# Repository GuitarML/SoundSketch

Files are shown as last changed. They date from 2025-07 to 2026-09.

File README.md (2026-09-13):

# SoundSketch

Hardware and software for Soundsketch guitar pedal as shown on [Youtube](https://youtu.be/grorq3XL0zQ?si=FIOID7Fv4AuRCGD6)

Borrows from the open source [DaisySeedProjects](https://github.com/bkshepherd/DaisySeedProjects) pedal, but expression and 3 way toggles, and screen/encoder, midi out removed. 

Not all of the Planet Series software modules ported from Funbox have been tested, some code editing may be required. 

IMPORTANT: When ordering assembled Soundsketch PCBs from JLCPcb or PCBway, you have to manually rotate certain components to the correct orientation on their online tool as part of the ordering process. This is required because the part data exported from KiCad to the .pos file is a different standard from what is expected by the manufacturer. Use the KiCad PCB view to verify correct orientation of ICs and diodes when compared to the manufacturer's parts visualization tool. 

Tayda Drill Template:
https://drill.taydakits.com/box-designs/new?public_key=MndaazFjcjJRM3hIUVQxenhPUm1Rdz09Cg==

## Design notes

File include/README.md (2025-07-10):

# Include
This contains the SoundSketch.h header along with custom headers for SoundSketch software.

## Contents
 - expressionHandler: Expression pedal code for the SoundSketch board. Remaps knob controls to use with an expression pedal.

 - SoundSketch.h : Include header file for SoundSketch.  This provides an abstraction for the knobs, switches, and LEDs when writing software for SoundSketch.```

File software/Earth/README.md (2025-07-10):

# Earth (Planet Series)

Earth is a digital plate reverb and octave pedal using the Dattorro algorithm.

app

The Reverb is a modified version of the Dattorro implementation in [VCV rack Plateau](https://github.com/ValleyAudio/ValleyRackFree/tree/main/src/Plateau). 
The polyoctave effect is from: [Terrarium-Poly-Octave](https://github.com/schult/terrarium-poly-octave).

## Controls

| Control | Description | Comment |
| --- | --- | --- |
| Ctrl 1 | PreDelay | Amount of predelay, up to around 700ms |
| Ctrl 2 | Mix  | Dry/Wet mix |
| Ctrl 3 | Decay  | Amount of decay |
| Ctrl 4 | Mod Depth | Intensity of Mod |
| Ctrl 5 | Mod Speed | Rate of Modulation  |
| Ctrl 6 | Filter | Left of center is high cut, right of center is low cut |
| 3-Way Switch 1 | Reverb Size | Left=Small, Center=Med, Right=Big |
| 3-Way Switch 2 | Octave  | Left=None, Center=Octave Up, Right=Octave Up and Down  |
| 3-Way Switch 3 | Footswitch Action | Left=Momentary Freeze, Center=Momentary Overdrive, Right=Momentary Octave | 
| FS 1 | Bypass/Engage |  |
| FS 2 | Footswitch Action | Perform action based on toggle switch 3 |
| LED 1 | Bypass Indicator |  |
| LED 2 | Preset Indicator |  |
| Audio In 1 | Mono In | Right channel ignored |
| Audio Out 1 | Stereo Out  | Stereo Out via TRS |
<br>
### Expression
1. Plug in passive expression pedal into the 1/8" jack on the top left side of pedal. (will need a 1/4" female to 1/8" male TRS adapter)<br>
2. Hold both footswitches until they both light up (more than 0.5 seconds, but less than 2 seconds), you are now in Set Expression mode.<br>
3. Move the expression pedal into the heel position (up) and move any number of knobs to where you want to heel limit to be (for example you could turn Volume down). The right LED should be brighter up to indicate the heel position is ready to set.*<br>
3. Move the expression pedal into the toe position (down) and move any number of knobs to where you want to toe limit to be (for example you could turn Volume up). The Left LED should be brighter to indicate the toe position is ready to set.*<br>
4. Hold both footswitches to exit Set Expression mode. This will activate expression for the moved knobs. The moved knobs will be inactive until Expression Mode is deactivated.<br>
5. Repeat step 2 to reset Expression knobs.<br>
6. Hold both footswitches for 2 seconds or more to clear any Expression action and give control back to the Funbox knobs.<br>
<br>
* Currently, the expression input requires the full range of the expression pedal, in order to detect Up/Down positions. You can sometimes trim the expression pedal to not use the full range, so adjust the trim as necessary.<br>
  Also, some expression pedals have a "Standard" or "Alternate/Other" mode. Funbox should work on the "Standard" mode.<br>

### MIDI Reference

| Control | MIDI CC | Value |
| --- | --- | --- |
| Knob 1 | 14 | 0- 127 |
| Knob 2 | 15 | 0- 127 |
| Knob 3 | 16 | 0- 127 |
| Knob 4 | 17 | 0- 127 |
| Knob 5 | 18 | 0- 127 |
| Knob 6 | 19 | 0- 127 |

## Build

Build with ```make```.

Earth is intended to be used as a submodule in Funbox, and build paths expect to be used as such. The Earth 
code was split out from the Funbox project to preserve the License used in reused/modified code from other projects. 
To build Earth, it is recommended to clone the Funbox project and run "git submodule update --init --recursive" 
to get Earth and all required dependencies. Otherwise, you can download the .bin executable to upload to the Daisy Seed 
from the Releases page.

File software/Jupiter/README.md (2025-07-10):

# Jupiter (Planet Series)

Jupiter is a Stereo Reverb pedal. The reverb used here is from the [CloudSeed plugin](https://github.com/ValdemarOrn/CloudSeed) (MIT License). It is the same reverb from the Neptune pedal, 
but more EQ controls are exposed to the user, specifically the post reverb low and high shelf filters, both the frequency cutoff and gain.

app

## Controls

| Control | Description | Comment |
| --- | --- | --- |
| Ctrl 1 | Reverb Decay | Increases the decay time of the reverb, about 300ms to 60 seconds, exponential taper (noon is 2 seconds decay) |
| Ctrl 2 | Low Shelf Frequency  | Log Taper 20Hz to 1000Hz, noon is about 200Hz |
| Ctrl 3 | High Shelf Frequency  | Log Taper 400 Hz to 20000Hz, noon is about 4300Hz |
| Ctrl 4 | Mix | Dry to Wet mix |
| Ctrl 5 | Low Shelf Gain | Low shelf cut, from 100% cut to 0.0 gain at max knob  |
| Ctrl 6 | High Shelf Gain | High shelf cut, from 100% cut to 0.0 gain at max knob |
| 3-Way Switch 1 | Lush Level | Amount of "Lushness", low, medium, high |
| 3-Way Switch 2 | Modulation Level  |  Sets the modulation amount and rate, low, medium, high  |
| 3-Way Switch 3 | PreDelay | Sets predelay, 0, 100ms, 200ms | 
| FS 1 | Bypass/Engage |  |
| FS 2 | Preset | Hold to save preset, press to engage/disengage preset. Saves between power cycles. |
| LED 1 | Bypass Indicator |  |
| LED 2 | Preset Indicator |  |
| Audio In 1 | Stereo In | Right channel ignored if MISO Mode turned on |
| Audio Out 1 | Stereo Out  |  |
<br>
### Expression
1. Plug in passive expression pedal into the 1/8" jack on the top left side of pedal. (will need a 1/4" female to 1/8" male TRS adapter)<br>
2. Hold both footswitches until they both light up (more than 0.5 seconds, but less than 2 seconds), you are now in Set Expression mode.<br>
3. Move the expression pedal into the heel position (up) and move any number of knobs to where you want to heel limit to be (for example you could turn Volume down). The right LED should be brighter up to indicate the heel position is ready to set.*<br>
3. Move the expression pedal into the toe position (down) and move any number of knobs to where you want to toe limit to be (for example you could turn Volume up). The Left LED should be brighter to indicate the toe position is ready to set.*<br>
4. Hold both footswitches to exit Set Expression mode. This will activate expression for the moved knobs. The moved knobs will be inactive until Expression Mode is deactivated.<br>
5. Repeat step 2 to reset Expression knobs.<br>
6. Hold both footswitches for 2 seconds or more to clear any Expression action and give control back to the Funbox knobs.<br>
<br>
* Currently, the expression input requires the full range of the expression pedal, in order to detect Up/Down positions. You can sometimes trim the expression pedal to not use the full range, so adjust the trim as necessary.<br>
  Also, some expression pedals have a "Standard" or "Alternate/Other" mode. Funbox should work on the "Standard" mode.<br>

### MIDI Reference

| Control | MIDI CC | Value |
| --- | --- | --- |
| Knob 1 | 14 | 0- 127 |
| Knob 2 | 15 | 0- 127 |
| Knob 3 | 16 | 0- 127 |
| Knob 4 | 17 | 0- 127 |
| Knob 5 | 18 | 0- 127 |
| Knob 6 | 19 | 0- 127 |

## Build

Before building Jupiter, you must build Cloudseed with ```make``` in the CloudSeed folder.

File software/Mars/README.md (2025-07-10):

# Mars (Planet Series)

Mars is an amp sim / delay pedal. It includes 3 neural models, 3 Impulse Responses (Cab Sim), and a delay effect with dotted 8th and triplett modes.

Neural Network inference for the amp/pedal models uses [RTNeural](https://github.com/jatinchowdhury18/RTNeural)
The Impluse Response code is a modified version of the IR processing in the [NAM plugin](https://github.com/sdatkinson/NeuralAmpModelerPlugin) (MIT License) 

Note: Due to the processing power required for the neural models and IRs, Mars is a mono effect, which on the Funbox pedal is copied left to right channel for output. 
If a stereo signal is going into the input, Mars will only take the left channel for processing.

app

## Controls

| Control | Description | Comment |
| --- | --- | --- |
| Ctrl 1 | Gain | Increases the input gain to the neural model |
| Ctrl 2 | Mix | Mix control between the amp and delay |
| Ctrl 3 | Level | Overall volume output |
| Ctrl 4 | Filter | Lowpass filter left of center, highpass right of center |
| Ctrl 5 | Delay Time | Delay time 0 to 2 seconds.  |
| Ctrl 6 | Delay Feedback | Delay Feedback (how long delay takes to fade out) |
| 3-Way Switch 1 | Amp/Model Select | 3 available models, default: left: Matchless SC30, center: Klon pedal, right: Mesa iib |
| 3-Way Switch 2 | IR Select |  3 available IRs, default: left: Proteus (from GuitarML Proteus plugin), center: American, right: Rectifier |
| 3-Way Switch 3 | Delay Mode | left: normal, center: dotted 8th, right: triplett |
| Dip Switch 1 | Amp On/Off | Engage/Disengage Neural model |
| Dip Switch 2 | IR On/Off| Engage/Disengage IR |
| FS 1 | Bypass |  |
| FS 2 | Preset | Hold to save preset, press to engage/disengage preset. Saves between power cycles. |
| LED 1 | Bypass Indicator |  |
| LED 2 | Preset Indicator |  ||
| Audio In 1 | Mono In (Left Channel) | Right channel ignored if using TRS  |
| Audio Out 1 | Mono Out  | Left channel copied to Right Channel if using TRS |

## Build

Mars runs in SRAM memory on the Daisy Seed. You must use the Bootloader to load the executable.

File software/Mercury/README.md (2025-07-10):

# Mercury (Planet Series)

Mercury is an amp sim using Neural Amp Modeler (NAM). It includes 9 custom size neural models and a 4 band EQ (Bass, Mid, Treble, Presence).
It is intended to be used with a separate IR/CabSim, or an actual amp (no cab modelling on Mercury).

Neural Network inference for the amp/pedal models uses [RTNeural](https://github.com/jatinchowdhury18/RTNeural) with [RTNeural-NAM](https://github.com/jatinchowdhury18/RTNeural-NAM).

Note: Due to the processing power required for the neural models, Mercury is a mono effect, which on the Funbox pedal is copied left to right channel for output. 
If a stereo signal is going into the input, Mercury will only take the left channel for processing.

app

*Models included:
Low Gain:
- Matchless SC30
- Twin Reverb
- Dumble Low Gain (from kit build)

Medium Gain:
- Dumble Higher Gain (from kit build)
- Ethos Tube Pedal
- JCM800 Medium Gain

High Gain:
- Mesa iib
- Splawn
- PRS Archon

## Controls

| Control | Description | Comment |
| --- | --- | --- |
| Ctrl 1 | Gain | Increases the input gain to the neural model up to 2.5x |
| Ctrl 2 | Level | Overall volume |
| Ctrl 3 | Presence | +10/-10 dB Presence control, center is 0. |
| Ctrl 4 | Bass | +10/-10 dB Bass control, center is 0. |
| Ctrl 5 | Mid | +10/-10 dB Mid control, center is 0.  |
| Ctrl 6 | Treble | +10/-10 dB Treble control, center is 0. |
| 3-Way Switch 1 | Amp/Model Group | 3 available groups, default: left: LowGain, center: MedGain, right: HighGain |
| 3-Way Switch 2 | NAM Model Select |  3 available NAM models for each group* |
| 3-Way Switch 3 | Unused |  |
| Dip Switch 1 | |  |
| Dip Switch 2 | |  |
| FS 1 | Bypass |  |
| FS 2 | Preset |  |
| LED 1 | Bypass Indicator |  |
| LED 2 | Preset Indicator |  ||
| Audio In 1 | Mono In (Left Channel) | Right channel ignored if using TRS  |
| Audio Out 1 | Mono Out  | Left channel copied to Right Channel if using TRS |

### MIDI Reference

| Control | MIDI CC | Value |
| --- | --- | --- |
| Knob 1 | 14 | 0- 127 |
| Knob 2 | 15 | 0- 127 |
| Knob 3 | 16 | 0- 127 |
| Knob 4 | 17 | 0- 127 |
| Knob 5 | 18 | 0- 127 |
| Knob 6 | 19 | 0- 127 |

## Build

Mercury runs in SRAM memory on the Daisy Seed. You must use the Bootloader to load the executable.

Mercury is intended to be used as a submodule in Funbox, and build paths expect to be used as such. The Mercury 
code was split out from the Funbox project to preserve the License used in reused/modified code from other projects. 
To build Mercury, it is recommended to clone the Funbox project and run "git submodule update --init --recursive" 
to get Mercury and all required dependencies. Otherwise, you can download the .bin executable to upload to the Daisy Seed 
from the Releases page.

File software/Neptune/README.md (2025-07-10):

# Neptune (Planet Series)

Neptune is a Stereo Reverb/Delay pedal. The reverb used here is from the [CloudSeed plugin](https://github.com/ValdemarOrn/CloudSeed) (MIT License), and the Delay includes normal, octave, and reverse modes.
Neptune is very similar to the GuitarML Atlas pedal. The reverse delay is a modified version of the reverse delay from [Veno-Echo](https://github.com/AdamFulford/Veno-Echo) (MIT License)

app

## Controls

| Control | Description | Comment |
| --- | --- | --- |
| Ctrl 1 | Reverb Decay | Increases the decay time of the reverb |
| Ctrl 2 | Mix (rev/delay mix)  | Mix control between the Dry input and effect, alternate is Reverb/Delay volume ratio |
| Ctrl 3 | Delay Time | Delay time from 0 to 4 seconds |
| Ctrl 4 | Mod (Mod Rate) | Amount of modulation of the reverb, Alternate mode sets is mod rate |
| Ctrl 5 | Reverb LowPass | Delay time 0 to 2 seconds.  |
| Ctrl 6 | Delay Feedback | Delay Feedback (how long delay takes to fade out) |
| 3-Way Switch 1 | Reverb Mode |  left: Factory Chorus, center: Medium Space, right: RubiKai (These mostly match the CloudSeed presets) |
| 3-Way Switch 2 | Routing |  left: Some delay fed to reverb, center: Parallel reverb/delay right: delay into reverb in series |
| 3-Way Switch 3 | Delay Mode | left: normal, center: octave, right: reverse |
| Dip Switch 1 | MISO/Stereo | MISO (Mono in stereo out), or True Stereo |
| Dip Switch 2 |  |  |
| FS 1 | Bypass, hold to put into Alternate mode | Alternate mode indicated by dimmed LED, switches back when let go |
| FS 2 | Preset | Hold to save preset, press to engage/disengage preset. Saves between power cycles. |
| LED 1 | Bypass/Alternate Indicator |  |
| LED 2 | Preset Indicator |  ||
| Audio In 1 | Stereo In | Right channel ignored if MISO Mode turned on |
| Audio Out 1 | Stereo Out  |  |
<br>
### Expression
1. Plug in passive expression pedal into the 1/8" jack on the top left side of pedal. (will need a 1/4" female to 1/8" male TRS adapter)<br>
2. Hold both footswitches until they both light up (more than 0.5 seconds, but less than 2 seconds), you are now in Set Expression mode.<br>
3. Move the expression pedal into the heel position (up) and move any number of knobs to where you want to heel limit to be (for example you could turn Volume down). The right LED should be brighter up to indicate the heel position is ready to set.*<br>
3. Move the expression pedal into the toe position (down) and move any number of knobs to where you want to toe limit to be (for example you could turn Volume up). The Left LED should be brighter to indicate the toe position is ready to set.*<br>
4. Hold both footswitches to exit Set Expression mode. This will activate expression for the moved knobs. The moved knobs will be inactive until Expression Mode is deactivated.<br>
5. Repeat step 2 to reset Expression knobs.<br>
6. Hold both footswitches for 2 seconds or more to clear any Expression action and give control back to the Funbox knobs.<br>
<br>
* Currently, the expression input requires the full range of the expression pedal, in order to detect Up/Down positions. You can sometimes trim the expression pedal to not use the full range, so adjust the trim as necessary.<br>
  Also, some expression pedals have a "Standard" or "Alternate/Other" mode. Funbox should work on the "Standard" mode.<br>

### MIDI Reference

| Control | MIDI CC | Value |
| --- | --- | --- |
| Knob 1 | 14 | 0- 127 |
| Knob 2 | 15 | 0- 127 |
| Knob 3 | 16 | 0- 127 |
| Knob 4 | 17 | 0- 127 |
| Knob 5 | 18 | 0- 127 |
| Knob 6 | 19 | 0- 127 |

## Build

Neptune runs in SRAM memory on the Daisy Seed. You must use the Bootloader to load the executable.
Note: MIDI will not work if you use the Bootloader from the Daisy Web Programmer (it's an old version).

Before building Neptune, you must build Cloudseed with ```make```

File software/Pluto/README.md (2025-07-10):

# Pluto

Pluto is a wacky dual/stereo looper for endless experimentation. Each looper features a variable speed control, smooth or stepped,
and several effects and loop modes. Pluto runs at 96kHz instead of 48kHz, in order to have the best quality when slowing down loops,
but don't worry, lots of aliasing/artifacts are present when strethching audio!

Loops are recorded at the current speed setting. For example, if the speed of Loop A is at 2x and you record a loop, it will sound normal, but turning the speed 
knob down to 1x will play your loop at half speed (and half the samplerate). 

Pluto is in active development, more features coming 

app

## Controls

| Control | Description | Comment |
| --- | --- | --- |
| Ctrl 1 | Looper A Volume |  |
| Ctrl 2 | Looper A Modify | Modifies the current effect applied to loop A (or for Reverb, controls decay time) |
| Ctrl 3 | Looper B Volume |  |
| Ctrl 4 | Looper A Speed/Direction | Speed and direction of Loop A, -2x (reverse) to +2x speed, noon is 1x speed |
| Ctrl 5 | Looper A Modify | Modifies the current effect applied to loop A (or for Reverb, controls decay time) |
| Ctrl 6 | Looper B Speed/Direction | Speed and direction of Loop B, -2x (reverse) to +2x speed, noon is 1x speed |  |
| 3-Way Switch 1 | Looper A/B Speed mode | Left = smooth, Center=Stepped, Right= TBD |
| 3-Way Switch 2 | Live effect select (controls what modify knobs do) | Left=Stability(random variations in playback speed), Center=Filter (LP to the left, HP to the right), Right=Reverb (stereo, ModA is decay, ModB is damping) |
| 3-Way Switch 3 | Loop Record Mode | Left = normal, Center = One Time loop record, Right= Frippertronics (when recording, acts like a delay, applying a decay time to the loop) |
| Dip Switch 1 | MISO/Stereo | Miso only takes the left channel input, and treats each looper as independant. Stereo takes L/R input and treats loopers as connected when recording (Looper B footswitch is inactive in Stereo Mode) |
| Dip Switch 2 | TBD | Want to add a Sync mode here, where the loop time for both A/B are equal |
| FS 1 | Loop A control | Tap once to start recording loop, tap again to stop record and start playback. Double tap to pause loop. Hold to clear loop. Tap again to overdub. Currently no undo function. |
| FS 2 | Loop B control | Same as Loop A |
| LED 1 | Loop A Indicator | Pulses while recording, Solid while playback, blinking while paused. |
| LED 2 | Loop B indicator | Same as Loop A|
| Audio In 1 | Stereo (or MISO) | MISO will use 2 speparate loopers, and copy left channel output to right, Stereo will use 1 looper, and loop A is left channel, loop B is right channel |
| Audio Out 1 | Stereo |  |

<br>
### Expression
Expression Operation: NOTE THAT THIS IS DIFFERENT FROM OTHER PLANET PEDALS**<br>
1. Plug in passive expression pedal into the 1/8" jack on the top left side of pedal. (will need a 1/4" female to 1/8" male TRS adapter)<br>
2. Turn on Dipswitch 3 to enter Set Expression mode, both LEDs should light up, you are now in Set Expression mode.<br>
3. Move the expression pedal into the heel position (up) and move any number of knobs to where you want to heel limit to be (for example you could turn Volume down). The right LED should be brighter up to indicate the heel position is ready to set.*<br>
3. Move the expression pedal into the toe position (down) and move any number of knobs to where you want to toe limit to be (for example you could turn Volume up). The Left LED should be brighter to indicate the toe position is ready to set.*<br>
4. Turn off Dipswitch 3 to exit Set Expression mode and enter Expression Active Mode. <br>
5. Flip Dipswitch 3 on and move expression pedal into both up and down positions without turning any knobs. Flip Dipswitch 3 off to clear expression and give control back to knobs.

<br>
* Currently, the expression input requires the full range of the expression pedal, in order to detect Up/Down positions. You can sometimes trim the expression pedal to not use the full range, so adjust the trim as necessary.<br>
  Also, some expression pedals have a "Standard" or "Alternate/Other" mode. Funbox should work on the "Standard" mode.<br>
<br>
** Since Pluto uses the footswitches for looper funtions, the third dip switch is used to enter/exit Set Expression mode. Flip dipswitch 3 without adjusting any knobs to clear expression settings.

### MIDI Reference

| Control | MIDI CC | Value |
| --- | --- | --- |
| Knob 1 | 14 | 0- 127 |
| Knob 2 | 15 | 0- 127 |
| Knob 3 | 16 | 0- 127 |
| Knob 4 | 17 | 0- 127 |
| Knob 5 | 18 | 0- 127 |
| Knob 6 | 19 | 0- 127 |
| Toggle Left | 21 | 0,1:left ; 2, center; 3 or > right |
| Toggle Center | 22 | 0,1:left ; 2, center; 3 or > right |
| Toggle Right| 23 | 0,1:left ; 2, center; 3 or > right |

## Build

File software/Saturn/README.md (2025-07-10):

# Saturn (Planet Series)

Saturn is a Spectral Delay. It works by using a FFT (Fast Fourier Transform) to split up your signal in the frequency domain and apply different delays to each frequency group. 
Saturn diffracts your signal into "particles", creating a kaleidoscope of sound from your guitar.

This code adapts the FFT code here to run on Funbox hardware:
https://github.com/amcerbu/DaisySTFT

app

## Controls

| Control | Description | Comment |
| --- | --- | --- |
| Ctrl 1 | PreDelay | Adds up to 1 second of delay prior to the spectral delay starting |
| Ctrl 2 | Mix  | Dry/Wet mix |
| Ctrl 3 | Filter  | Lowpass to the left, Highpass to the right |
| Ctrl 4 | Time | 0 to 4 seconds of delay spread in the frequency bins, exact action determined by time toggle |
| Ctrl 5 | Feedback | Amount of feedback, depending on the FDBK toggle  |
| Ctrl 6 | DriftMod | Oscillation rate for drift, 0 to 1Hz |
| 3-Way Switch 1 | Time Mode | Left= Linear increase of delay time as frequency increases (TimeMod controls slope), Center= Sine wave of delay times across frequencies (TimeMod controls frequency) , Right= Random delay time for each line (TimeMod controls spread) |
| 3-Way Switch 2 | Feedback Mode  | Left=Same FDBK across delaylines , Center=linear decrease with frequency increase , Right= random amount of fdbk for each delayline |
| 3-Way Switch 3 | Drift | Left= Predelay not included, modulates delaytime and delayfeedback; Center= No Drift ; Right= Predelay included in drift, causing pitch warping sounds from modulating the predelay line | 
| Dip Switch 1 | Mono (off) / Stereo(on) | Mono mode uses the right channel's delay lines to double the frequency bins used in the spectral delay, (MONO overrides MISO/Stereo switch |
| Dip Switch 2 | MISO (off) /Stereo (on) | MISO (Mono in stereo out), or True Stereo |
| Dip Switch 3 | Stereo Spread Off/On | Places each frequency bin at a random point in the stereo field |
| Dip Switch 4 | On adds feedback of 0.75 to the Predelay |  |
| FS 1 | Bypass/Engage |  |
| FS 2 | Preset | Hold to save preset, press to engage/disengage preset. Saves between power cycles. |
| LED 1 | Bypass Indicator |  |
| LED 2 | Preset Indicator |  |
| Audio In 1 | Stereo In | Right channel ignored if in Mono or MISO mode |
| Audio Out 1 | Stereo Out  | Left channel copied to right if in Mono mode |
<br>
### Expression
1. Plug in passive expression pedal into the 1/8" jack on the top left side of pedal. (will need a 1/4" female to 1/8" male TRS adapter)<br>
2. Hold both footswitches until they both light up (more than 0.5 seconds, but less than 2 seconds), you are now in Set Expression mode.<br>
3. Move the expression pedal into the heel position (up) and move any number of knobs to where you want to heel limit to be (for example you could turn Volume down). The right LED should be brighter up to indicate the heel position is ready to set.*<br>
3. Move the expression pedal into the toe position (down) and move any number of knobs to where you want to toe limit to be (for example you could turn Volume up). The Left LED should be brighter to indicate the toe position is ready to set.*<br>
4. Hold both footswitches to exit Set Expression mode. This will activate expression for the moved knobs. The moved knobs will be inactive until Expression Mode is deactivated.<br>
5. Repeat step 2 to reset Expression knobs.<br>
6. Hold both footswitches for 2 seconds or more to clear any Expression action and give control back to the Funbox knobs.<br>
<br>
* Currently, the expression input requires the full range of the expression pedal, in order to detect Up/Down positions. You can sometimes trim the expression pedal to not use the full range, so adjust the trim as necessary.<br>
  Also, some expression pedals have a "Standard" or "Alternate/Other" mode. Funbox should work on the "Standard" mode.<br>

### MIDI Reference

| Control | MIDI CC | Value |
| --- | --- | --- |
| Knob 1 | 14 | 0- 127 |
| Knob 2 | 15 | 0- 127 |
| Knob 3 | 16 | 0- 127 |
| Knob 4 | 17 | 0- 127 |
| Knob 5 | 18 | 0- 127 |
| Knob 6 | 19 | 0- 127 |

## Build

Saturn compiles for FLASH memory on the Daisy Seed using the standard upload procedure.

## Technical Info:
Saturn uses a FFT with N=1024 and laps=4 (4 overlapping hann windows). This splits the frequencies into N/2=512 frequency bins. 

At 48000kHz samplerate, the bins are split into (samplerate / 2 / #bins) = 46.875 Hz per bin. 

Each bin output is applied to a separate delayline with different time/feedback to create the Spectral Delay. 
I use two DaisySP delaylines for each bin, one for the real component and one for the imaginary component. 

In order to run on the Daisy Seed in Stereo (using two FFTs), the maximum number of bins with delaylines I was able to use was 175. Using
more than 175 caused audio dropouts when running at 48kHz samplerate. You can utilize more bins by running at a lower samplerate, such as 32kHz.

The frequency range of the spectral delay is (#bins * 46.875) = 8203Hz. This is nowhere near the full audible spectrum, but it still sounds pretty good.

When using Mono mode (dipswitch 1 in the off position), I'm able to use 350 frequency bins for a range of 16406Hz, much closer to the full range of the audible frequencies.
See if you can hear the difference!

The custom FFT function "spectraldelay()" and "spectraldelay2()" (for the right channel) is called every N/laps, so 1024/4=256 samples. 
At 48kHz, this means that the spectraldelay function is called 48000/256 = 187.5 times per second. This means that even though we use 
a relatively large number of delaylines, each one only needs to have a size of 187.5 * 4 = 750 for a max of 4 seconds of delay. (compared to 48000 samples per second in the time domain).

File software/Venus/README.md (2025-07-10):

# Venus

Venus is a Spectral Reverb that uses a STFT (Short time Fourier Transform) to operate on your signal in the frequency
domain. It can create lush soundscapes with string-like overtones, detuning, and spectral freeze.  It features
two LoFi modes that reduce the samplerate and two "drift" modes that modulate knob values slowly over time. 

Notes: The Venus pedal runs at 32kHz samplerate and buffersize of 256 in order to run smoothly with the current STFT implementation.
Improving the efficiency of the STFT to run at higher samplerates and lower buffersize is of interest.

app

## Controls

| Control | Description | Comment |
| --- | --- | --- |
| Ctrl 1 | Decay | Decay time of reverb |
| Ctrl 2 | Mix | Dry/Wet mix |
| Ctrl 3 | Damp | Reverb dampening |
| Ctrl 4 | Shimmer Amount | Adds octave shimmer |
| Ctrl 5 | Shimmer Tone | Adds in octave + 5ths to shimmer |
| Ctrl 6 | Detune | Left of noon detunes down, right of noon detunes up |
| 3-Way Switch 1 | Shimmer Mode | left=octave down, center= octave up, right=octave up and octave down |
| 3-Way Switch 2 | LoFi Mode (lofi applied to wet mix only, not dry mix) | left= samplerate of 9600 with lowpass filter, center=None, right= samplerate of 6400, no lowpass filter |
| 3-Way Switch 3 | Drift Mode | left=same as right except at a rate of ~50 seconds, center=none, right=more, oscillates the Damp, Shimmer, ShimmerTone, and Detune controls from the current setting to 0 at a rate of 1 cycle per ~25 seconds |
| Dip Switch 1 | N/A |  |
| Dip Switch 2 | N/A |  |
| Dip Switch 3 | N/A |  |
| Dip Switch 4 | N/A |  |
| FS 1 | Bypass/Engage |  |
| FS 2 | Freeze |  |
| LED 1 | Bypass indicator |  |
| LED 2 | Freeze indicator | |
| Audio In 1 | Mono in | |
| Audio Out 1 | Mono out (left copied to right) |  |

### Expression
1. Plug in passive expression pedal into the 1/8" jack on the top left side of pedal. (will need a 1/4" female to 1/8" male TRS adapter)<br>
2. Hold left footswitche until they both LEDS blink (more than 0.6 seconds, but less than 2 seconds), you are now in Set Expression mode.<br>
3. Move the expression pedal into the heel position (up) and move any number of knobs to where you want to heel limit to be (for example you could turn Volume down). The right LED should be brighter up to indicate the heel position is ready to set.*<br>
3. Move the expression pedal into the toe position (down) and move any number of knobs to where you want to toe limit to be (for example you could turn Volume up). The Left LED should be brighter to indicate the toe position is ready to set.*<br>
4. Hold left footswitch to exit Set Expression mode. This will activate expression for the moved knobs. The moved knobs will be inactive until Expression Mode is deactivated.<br>
5. Repeat step 2 to reset Expression knobs.<br>
6. Hold left footswitch for 2 seconds or more to clear any Expression action and give control back to the Funbox knobs.<br>
<br>
* Currently, the expression input requires the full range of the expression pedal, in order to detect Up/Down positions. You can sometimes trim the expression pedal to not use the full range, so adjust the trim as necessary.<br>
  Also, some expression pedals have a "Standard" or "Alternate/Other" mode. Funbox should work on the "Standard" mode.<br>

### MIDI Reference

| Control | MIDI CC | Value |
| --- | --- | --- |
| Knob 1 | 14 | 0- 127 |
| Knob 2 | 15 | 0- 127 |
| Knob 3 | 16 | 0- 127 |
| Knob 4 | 17 | 0- 127 |
| Knob 5 | 18 | 0- 127 |
| Knob 6 | 19 | 0- 127 |

## Build

Venus runs in Flash memory on the Daisy Seed.

## Acknowledgements

This code adapts the code found here to run a STFT on the Daisy Seed:
https://github.com/amcerbu/DaisySTFT

Which uses the "shyfft" authored by Émilie Gillet of Mutable Instruments:
https://github.com/pichenettes/eurorack

The math used in this reverb is heavily inspired by the Atlantis Reverb by Geraint Luff:
https://geraintluff.github.io/jsfx/#Atlantis%20Reverb

And directly from the examples in this forum post by Geraint Luff:
https://forum.cockos.com/showthread.php?t=225955

The Venus pedal would not be possible without the generosity of smart people sharing their work in the open source community. Thank you!

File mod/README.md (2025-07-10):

# libDaisy Modifications

Replace these files in libDaisy before building libDaisy. This is required to correctly map the controls for SoundSketch hardware.

<br><br>
INSTRUCTIONS:
```
# Replace libDaisy/src/daisy_pedal.h with SoundSketch/mod/daisy_pedal.h
# Replace libDaisy/src/daisy_pedal.cpp with SoundSketch/mod/daisy_pedal.cpp

make -C libDaisy
```

## bksheperd hardware module definitions

These are the hardware definitions for using the bksheperd guitar pedal framework on the SoundSketch. 
Add these two files to the following location in your [DaisySeedProjects](https://github.com/bkshepherd/DaisySeedProjects/tree/main) repo and update 
the guitar_pedal.cpp to use this hardware definition.

Add the guitar_pedal_soundsketch.h and guitar_pedal_soundsketch.cpp file to this location to use this extensive guitar effect framework on the SoundSketch:
https://github.com/bkshepherd/DaisySeedProjects/tree/main/Software/GuitarPedal/Hardware-Modules

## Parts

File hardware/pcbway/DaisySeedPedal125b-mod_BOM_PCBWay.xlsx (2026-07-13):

 |  |  | xxxx xxxx xxxxx xxPCS BOM (Sample Bill of Materials)
Item # | *Designator | *Qty | Manufacturer | *Mfg Part # | Description / Value | *Package/Footprint | Type | Your Instructions / Notes
1 | U4 | 1 | Everlight Elec | H11L1S(TA) | 3V~15V DC SOP-6-2.54mm Logic Output Optoisolators ROHS | SOP-6_2.54mm | SMD
2 | R20 | 1 | UNI-ROYAL(Uniroyal Elec) | 0805W8F4700T5E | 125mW Thick Film Resistors 150V ±100ppm/℃ ±1% 470Ω 0805 Chip Resistor - Surface Mount ROHS | 805 | SMD
3 | J7,J6 | 2 | BOOMELE(Boom Precision Elec) | 2.54-1*20PFemale | 1x20 Through Hole Header | Plugin,P=2.54mm | thru-hole | If these are expensive or difficult to source, I can handle the 20 pin headers myself (customer)
4 | R11,R1,R2,R12,R5,R10,R15,R18,R16,R4,R9 | 11 | UNI-ROYAL(Uniroyal Elec) | 0805W8F2004T5E | 125mW Thick Film Resistors 150V ±100ppm/℃ ±1% 2MΩ 0805 Chip Resistor - Surface Mount ROHS | 805 | SMD
5 | K2,K1 | 2 | Omron Electronics | G6K-2G-Y DC5 | Two Sets of Conversion: 2C (DPDT-Conversion) 1A 5V SMD,6.5x10mm Signal Relays ROHS | SMD,6.5x10mm | SMD
6 | U3 | 1 | Texas Instruments | OPA1652AIDR | Dual Channel SOIC-8 Audio Amplifiers ROHS | SOIC-8 | SMD
7 | U2 | 1 | Microchip Tech | MCP6004T-I/SL | Four channels 1pA 0.6V/us 1MHz Rail-to-rail input, rail-to-rail output 4.5mV SOIC-14 Operational Amplifier ROHS | SOIC-14 | SMD
8 | R14,R13 | 2 | UNI-ROYAL(Uniroyal Elec) | 0805W8F1000T5E | 125mW Thick Film Resistors 150V ±100ppm/℃ ±1% 100Ω 0805 Chip Resistor - Surface Mount ROHS | 805 | SMD
9 | C10,C9 | 2 | Samsung Electro-Mechanics | CL21C222JBFNNNE | 50V 2.2nF C0G ±5% 0805 Multilayer Ceramic Capacitors MLCC - SMD/SMT ROHS | 805 | SMD
10 | C1,C8,C7,C12,C4,C11,C16,C15 | 8 | Samsung Electro-Mechanics | CL21A106KAYNNNE | 25V 10uF X5R ±10% 0805 Multilayer Ceramic Capacitors MLCC - SMD/SMT ROHS | 805 | SMD
11 | R23,R22,R21,R25,R24 | 5 | UNI-ROYAL(Uniroyal Elec) | 0805W8F1001T5E | 125mW Thick Film Resistors 150V ±100ppm/℃ ±1% 1kΩ 0805 Chip Resistor - Surface Mount ROHS | 805 | SMD
12 | D3,D4 | 2 | Shandong Jingdao Microelectronics | 1N4007W | 1A Independent Type 1kV 1.1V@1A SOD-123FL Diodes - General Purpose ROHS | SOD-123FL | SMD
13 | R7,R8 | 2 | UNI-ROYAL(Uniroyal Elec) | 0805W8F3301T5E | 125mW Thick Film Resistors 150V ±100ppm/℃ ±1% 3.3kΩ 0805 Chip Resistor - Surface Mount ROHS | 805 | SMD
14 | C14,C13,C3,C2,C6,C17,C5 | 7 | YAGEO | CC0805KRX7R9BB104 | 50V 100nF X7R ±10% 0805 Multilayer Ceramic Capacitors MLCC - SMD/SMT ROHS | 805 | SMD
15 | U7 | 1 | Microchip Tech | MCP6002T-I/SN | Dual 1pA 0.6V/us 1MHz SOIC-8 Operational Amplifier ROHS | SOIC-8 | thru-hole
16 | U5,U6 | 2 | Littelfuse/IXYS | CPC1018NTR | 1 Form A(SPST-NO) 1.2V 60V 580mΩ 600mA SOP-4-2.54mm Solid State Relays (MOS Output) ROHS | SOP-4-2.54mm | SMD
17 | R3,R6 | 2 | UNI-ROYAL(Uniroyal Elec) | 0805W8F1003T5E | 125mW Thick Film Resistors 150V ±100ppm/℃ ±1% 100kΩ 0805 Chip Resistor - Surface Mount ROHS | 805 | SMD
18 | D2 | 1 | ST(Semtech) | 1N4148W | 75V Independent Type 1V@50mA 4ns 150mA SOD-123 Switching Diodes ROHS | SOD-123 | SMD
19 | J2, J4, J5, J9 | 4 | Neutrik | NMJ6HCD2 | Audio Connectors (Headphones) ROHS |  | thru-hole
20 | U1 | 1 | STMicroelectronics | LD1117S50CTR | 75dB@(120Hz) 800mA Fixed 5V Positive electrode 15V SOT-223-3 Voltage Regulators - Linear, Low Drop Out (LDO) Regulators ROHS | SOT-223-3 | SMD
21 | R17 | 1 | UNI-ROYAL(Uniroyal Elec) | 0805W8F2200T5E | 125mW Thick Film Resistors 150V ±100ppm/℃ ±1% 220Ω 0805 Chip Resistor - Surface Mount ROHS | 805 | SMD
22 | D1 | 1 | TWGMC | 1N5817W | 20V Independent Type 750mV@3A 1A SOD-123 Schottky Diodes ROHS | SOD-123 | SMD
23 | Q1 | 1 | Jiangsu Changjing Electronics Technology Co., Ltd. | SS8050 | 25V 300mW 200@100mA,1V 1.5A NPN SOT-23 Bipolar (BJT) ROHS | SOT-23-3 | SMD

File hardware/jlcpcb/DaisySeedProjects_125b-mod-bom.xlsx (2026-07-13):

Comment | Designator | Footprint | JLCPCB Part #（optional）
H11L1 | U4 | SOP-6_2.54mm | C78589
470R | R20 | 805 | C17710
1x20 Through Hole Header | J7,J6 |  | C50984
2M | R11,R1,R2,R12,R5,R10,R15,R18,R16,R4,R9 | 805 | C26112
G6K-2G-Y DC5 | K2,K1 | SMD,6.5x10mm | C397140
OPA1652AIDR | U3 | SOIC-8 | C30025
MCP6004T-I/SL | U2 | SOIC-14 | C7378
100R | R14,R13 | 805 | C17408
2.2NF | C10,C9 | 805 | C28260
10UF | C1,C8,C7,C12,C4,C11,C16,C15 | 805 | C15850
1K | R23,R22,R21,R25,R24 | 805 | C17513
1N4007W | D3,D4 | SOD-123FL | C108803
3.3K | R7,R8 | 805 | C26010
100NF | C14,C13,C3,C2,C6,C17,C5 | 805 | C49678
MCP6002T-I/SN | U7 | SOIC-8 | C7377
CPC1018N | U5,U6 | SOP-4-2.54mm | C133069
100K | R3,R6 | 805 | C149504
1N4148W | D2 | SOD-123 | C81598
NMJ6HCD2 | J2, J4, J5, J9 |  | C368502
LD1117S50CTR | U1 | SOT-223-3 | C81157
220R | R17 | 805 | C17557
1N5817 | D1 | SOD-123 | C727113
SS8050 | Q1 | SOT-23-3 | C2150

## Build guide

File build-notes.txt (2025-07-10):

1. Trim the backside midi and expression solder pin joints, they are too tall to fit potentiometers on top. 
   Put potentiometer covers on the bottom of the potentiometers, or they will short out the midi and expression jack leads.

2. Solder potentiometers. Install board into enclosure with potentiometers and switches in place, and tighten jack nuts. 
   This will ensure everything is set properly before soldering. Solder the 6 potentiometers (BUT NOT THE TOGGLE SWITCHES YET).

3. Remove the pcb and inspect. 

4. Solder toggles. VERY IMPORTANT: APPLY ELECTRICAL TAPE TO OUTSIDE OF TOGGLE BLOCKS, OTHERWISE WILL SHORT
   OUT ON THE SIDES OF THE POTENTIOMETER LEADS. Install toggles on pcb, then put pcb into enclosure, tightening
   everything in place (including 4 audio/exp/midi jacks) as with the potentiometers to ensure proper fit. 
   Solder the 3 toggle switches.

5. Solder the 2 LEDs on the pcb. Trim LED leads as neccessary, testing fit into LED bezels before soldering. 
   Solder LEDs onto the pcb and test fit in enclosure. 

6. Solder the power jack wires to the pcb with pcb not installed in enclosure. There is not much room
   in the enclosure with the pcb installed so this makes it easer to solder the power wires. 

7. Install pcb back into enclosure, then fit power jack and power jack nut into enclosure. There is not much room
   between the power jack nut and pcb. Solder the power jack wires to the power jack leads. 

8. Solder the 4 momentary footswitch wires to the momentary footswitches before installing into the enclosure.
   Its easier to do this first. Then install the footswitches into the enclosure and solder footswitch wires to the pcb.

9. Tighten all nuts. Visually inspect and check for anything loose. 

10. Install Daisy Seed and test.

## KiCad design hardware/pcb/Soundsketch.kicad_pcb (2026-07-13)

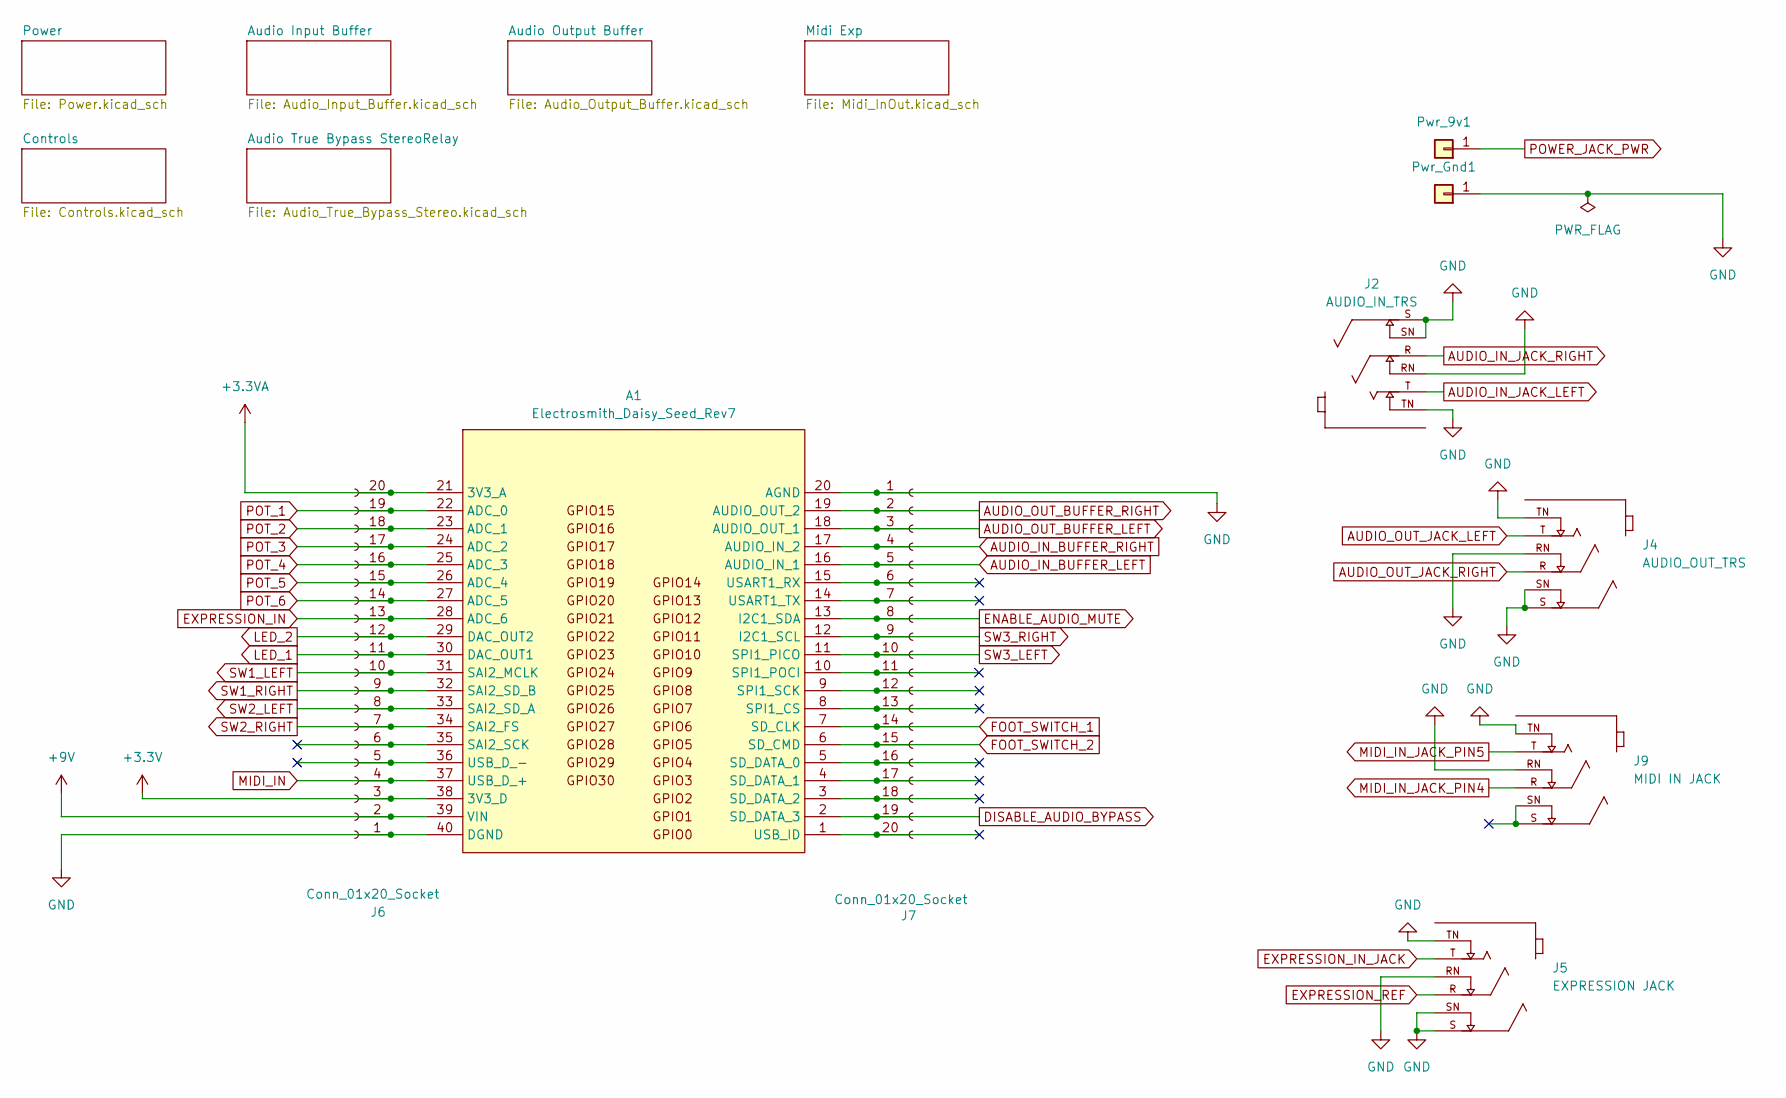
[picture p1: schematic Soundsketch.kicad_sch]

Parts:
A1: Electrosmith_Daisy_Seed_Rev7
J2: AUDIO_IN_TRS; NEUTRIK_NMJ6HCD2; PARTREV 26.02.2021
J4: AUDIO_OUT_TRS; NEUTRIK_NMJ6HCD2; PARTREV 26.02.2021
J5: EXPRESSION JACK; NEUTRIK_NMJ6HCD2; PARTREV 26.02.2021
J6, J7: Conn_01x20_Socket; PinSocket1x20_P2.54mm_Vertical_JLCPCB
J9: MIDI IN JACK; NEUTRIK_NMJ6HCD2; PARTREV 26.02.2021
Pwr_9v1: TestPoint_THTPad_D2.0mm_Drill1.0mm
Pwr_Gnd1: TestPoint_THTPad_D2.0mm_Drill1.0mm

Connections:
+3.3V: A1.38 (3V3_D), J6.3; also elsewhere on the board
+3.3VA: A1.21 (3V3_A), J6.20; also elsewhere on the board
+9V: A1.39 (VIN), J6.2; also elsewhere on the board
AUDIO_IN_BUFFER_LEFT: A1.16 (AUDIO_IN_1), J7.5; also elsewhere on the board
AUDIO_IN_BUFFER_RIGHT: A1.17 (AUDIO_IN_2), J7.4; also elsewhere on the board
AUDIO_IN_JACK_LEFT: J2.T; also elsewhere on the board
AUDIO_IN_JACK_RIGHT: J2.R; also elsewhere on the board
AUDIO_OUT_BUFFER_LEFT: A1.18 (AUDIO_OUT_1), J7.3; also elsewhere on the board
AUDIO_OUT_BUFFER_RIGHT: A1.19 (AUDIO_OUT_2), J7.2; also elsewhere on the board
AUDIO_OUT_JACK_LEFT: J4.T; also elsewhere on the board
AUDIO_OUT_JACK_RIGHT: J4.R; also elsewhere on the board
DISABLE_AUDIO_BYPASS: A1.2 (SD_DATA_3), J7.19; also elsewhere on the board
ENABLE_AUDIO_MUTE: A1.13 (I2C1_SDA), J7.8; also elsewhere on the board
EXPRESSION_IN: A1.28 (ADC_6), J6.13; also elsewhere on the board
EXPRESSION_IN_JACK: J5.T; also elsewhere on the board
EXPRESSION_REF: J5.R; also elsewhere on the board
FOOT_SWITCH_1: A1.7 (SD_CLK), J7.14; also elsewhere on the board
FOOT_SWITCH_2: A1.6 (SD_CMD), J7.15; also elsewhere on the board
GND: A1.20 (AGND), A1.40 (DGND), J2.RN, J2.S, J2.SN, J2.TN, J4.RN, J4.S, J4.SN, J4.TN, J5.RN, J5.S, J5.SN, J5.TN, J6.1, J7.1, J9.RN, J9.TN, Pwr_Gnd1.1; also elsewhere on the board
LED_1: A1.30 (DAC_OUT1), J6.11; also elsewhere on the board
LED_2: A1.29 (DAC_OUT2), J6.12; also elsewhere on the board
MIDI_IN: A1.37 (USB_D_+), J6.4; also elsewhere on the board
MIDI_IN_JACK_PIN4: J9.R; also elsewhere on the board
MIDI_IN_JACK_PIN5: J9.T; also elsewhere on the board
unnamed: A1.1 (USB_ID), J7.20
unnamed: A1.3 (SD_DATA_2), J7.18
unnamed: A1.4 (SD_DATA_1), J7.17
unnamed: A1.5 (SD_DATA_0), J7.16
unnamed: A1.8 (SPI1_CS), J7.13
unnamed: A1.9 (SPI1_SCK), J7.12
unnamed: A1.14 (USART1_TX), J7.7
unnamed: A1.15 (USART1_RX), J7.6
unnamed: A1.35 (SAI2_SCK), J6.6
unnamed: A1.36 (USB_D_-), J6.5
unnamed: A1.10 (SPI1_POCI), J7.11
POT_1: A1.22 (ADC_0), J6.19; also elsewhere on the board
POT_2: A1.23 (ADC_1), J6.18; also elsewhere on the board
POT_3: A1.24 (ADC_2), J6.17; also elsewhere on the board
POT_4: A1.25 (ADC_3), J6.16; also elsewhere on the board
POT_5: A1.26 (ADC_4), J6.15; also elsewhere on the board
POT_6: A1.27 (ADC_5), J6.14; also elsewhere on the board
POWER_JACK_PWR: Pwr_9v1.1; also elsewhere on the board
SW1_LEFT: A1.31 (SAI2_MCLK), J6.10; also elsewhere on the board
SW1_RIGHT: A1.32 (SAI2_SD_B), J6.9; also elsewhere on the board
SW2_LEFT: A1.33 (SAI2_SD_A), J6.8; also elsewhere on the board
SW2_RIGHT: A1.34 (SAI2_FS), J6.7; also elsewhere on the board
SW3_LEFT: A1.11 (SPI1_PICO), J7.10; also elsewhere on the board
SW3_RIGHT: A1.12 (I2C1_SCL), J7.9; also elsewhere on the board

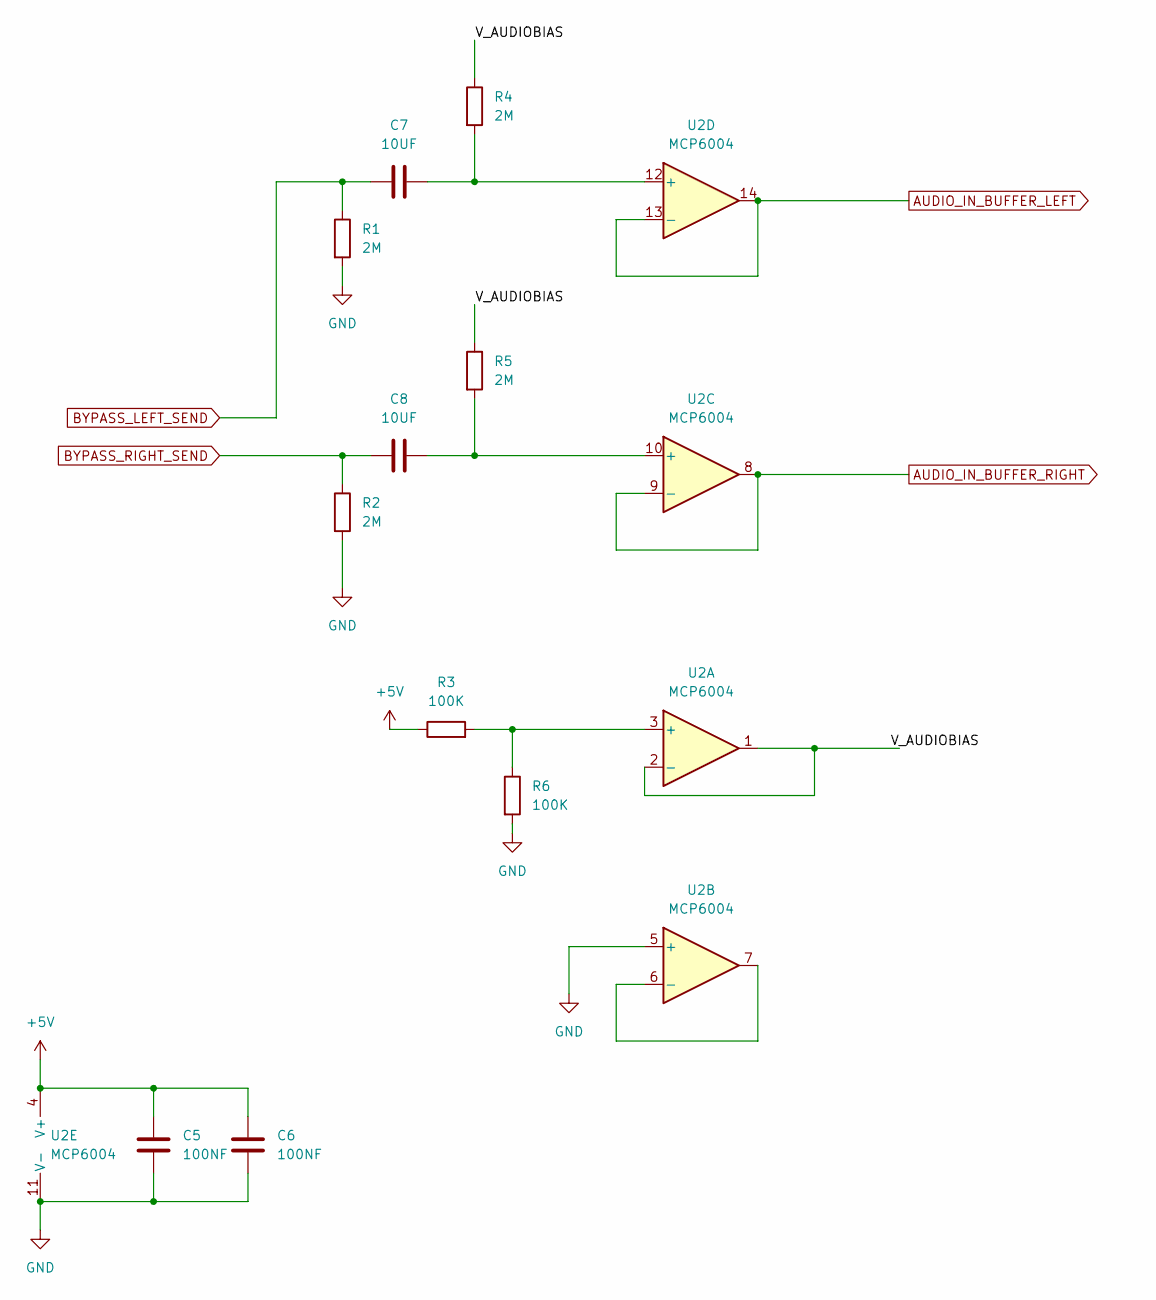
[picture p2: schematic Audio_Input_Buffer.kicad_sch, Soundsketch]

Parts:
C5, C6: 100NF; C_0805_2012Metric
C7, C8: 10UF; C_0805_2012Metric
R1, R2, R4, R5: 2M; R_0805_2012Metric
R3, R6: 100K; R_0805_2012Metric
U2: MCP6004; SOIC-14_3.9x8.7mm_P1.27mm

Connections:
+5V: C5.1, C6.1, R3.1, U2.4 (V+); also elsewhere on the board
/Audio Input Buffer/V_AUDIOBIAS: R4.1, R5.1, U2.1, U2.2 (-)
AUDIO_IN_BUFFER_LEFT: U2.13 (-), U2.14; also elsewhere on the board
AUDIO_IN_BUFFER_RIGHT: U2.8, U2.9 (-); also elsewhere on the board
BYPASS_LEFT_SEND: C7.1, R1.1; also elsewhere on the board
BYPASS_RIGHT_SEND: C8.1, R2.1; also elsewhere on the board
GND: C5.2, C6.2, R1.2, R2.2, R6.2, U2.5 (+), U2.11 (V-); also elsewhere on the board
unnamed: R3.2, R6.1, U2.3 (+)
unnamed: U2.6 (-), U2.7
unnamed: C8.2, R5.2, U2.10 (+)
unnamed: C7.2, R4.2, U2.12 (+)

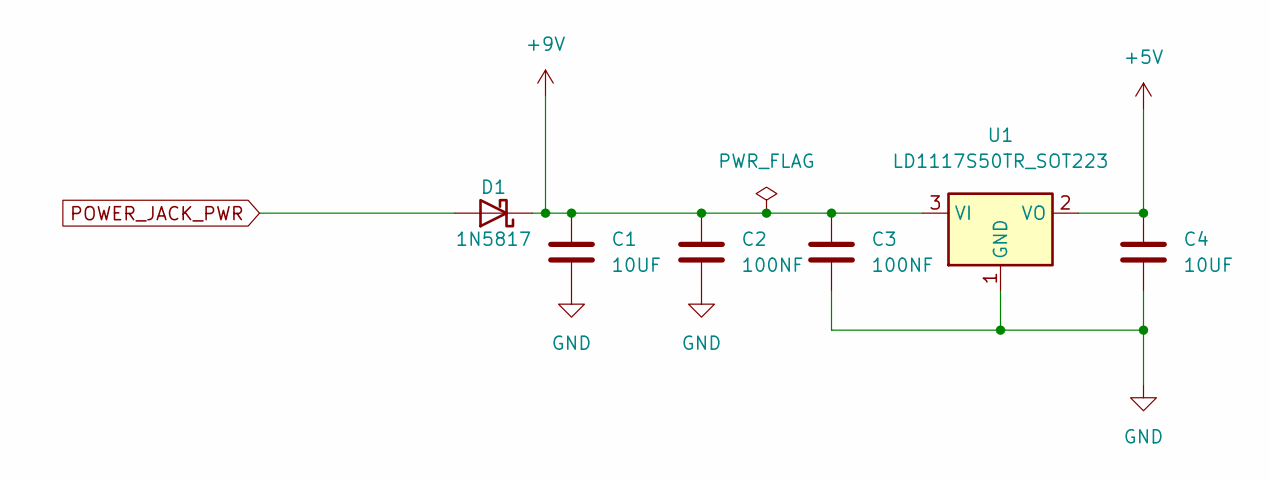
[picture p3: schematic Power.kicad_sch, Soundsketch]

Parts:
C1, C4: 10UF; C_0805_2012Metric
C2, C3: 100NF; C_0805_2012Metric
D1: 1N5817; D_SOD-123
U1: LD1117S50TR_SOT223; SOT-223-3_TabPin2

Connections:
+5V: C4.1, U1.2 (VO); also elsewhere on the board
+9V: C1.1, C2.1, C3.1, D1.1 (K), U1.3 (VI); also elsewhere on the board
GND: C1.2, C2.2, C3.2, C4.2, U1.1 (GND); also elsewhere on the board
POWER_JACK_PWR: D1.2 (A); also elsewhere on the board

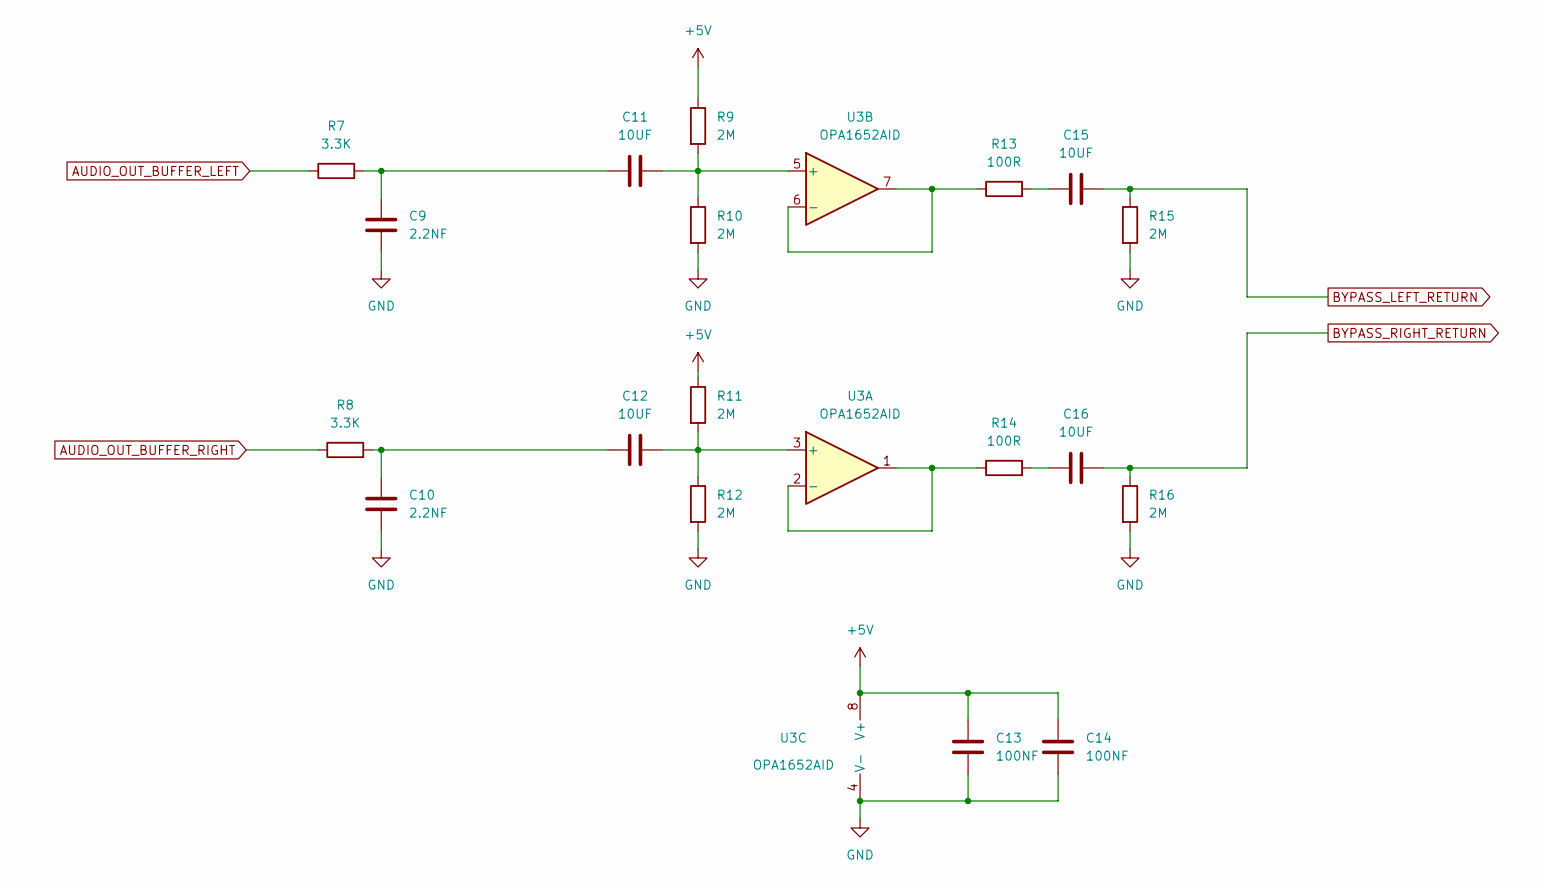
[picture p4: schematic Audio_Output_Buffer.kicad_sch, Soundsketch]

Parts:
C9, C10: 2.2NF; C_0805_2012Metric
C11, C12, C15, C16: 10UF; C_0805_2012Metric
C13, C14: 100NF; C_0805_2012Metric
R7, R8: 3.3K; R_0805_2012Metric
R9, R10, R11, R12, R15, R16: 2M; R_0805_2012Metric
R13, R14: 100R; R_0805_2012Metric
U3: OPA1652AID; SOIC-8_3.9x4.9mm_P1.27mm

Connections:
+5V: C13.1, C14.1, R9.1, R11.1, U3.8 (V+); also elsewhere on the board
AUDIO_OUT_BUFFER_LEFT: R7.1; also elsewhere on the board
AUDIO_OUT_BUFFER_RIGHT: R8.1; also elsewhere on the board
BYPASS_LEFT_RETURN: C15.2, R15.1; also elsewhere on the board
BYPASS_RIGHT_RETURN: C16.2, R16.1; also elsewhere on the board
GND: C9.2, C10.2, C13.2, C14.2, R10.2, R12.2, R15.2, R16.2, U3.4 (V-); also elsewhere on the board
unnamed: C10.1, C12.2, R8.2
unnamed: C9.1, C11.2, R7.2
unnamed: C15.1, R13.2
unnamed: C16.1, R14.2
unnamed: C12.1, R11.2, R12.1, U3.3 (+)
unnamed: R14.1, U3.1, U3.2 (-)
unnamed: C11.1, R9.2, R10.1, U3.5 (+)
unnamed: R13.1, U3.6 (-), U3.7

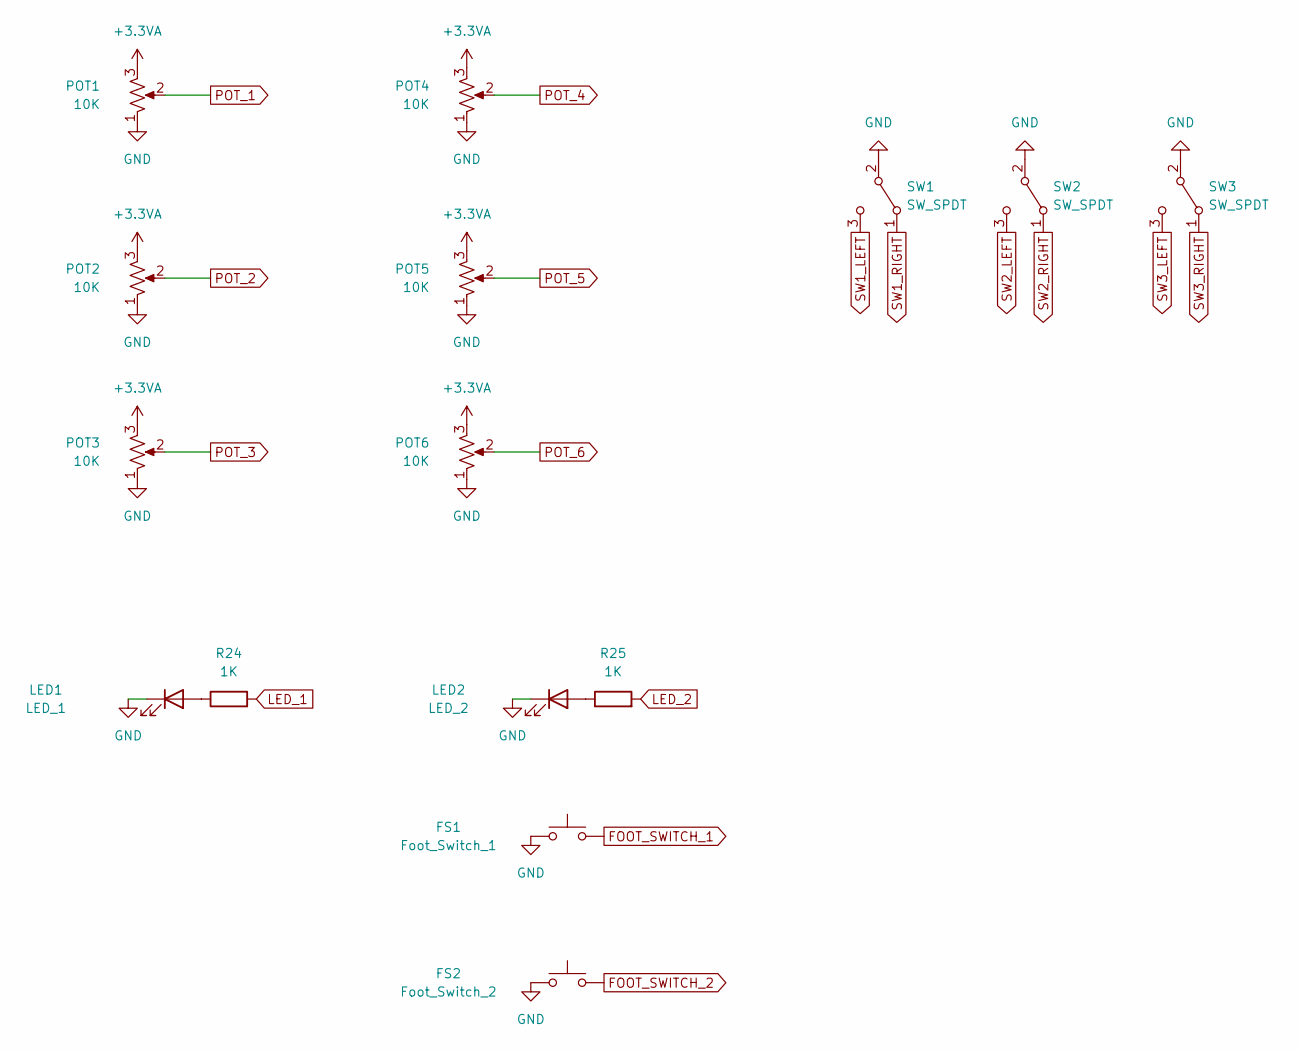
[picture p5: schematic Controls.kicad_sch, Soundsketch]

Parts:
FS1: Foot_Switch_1; PinHeader_1x02_P2.54mm_Vertical
FS2: Foot_Switch_2; PinHeader_1x02_P2.54mm_Vertical
LED1: LED_1; PinHeader_1x02_P2.54mm_Vertical
LED2: LED_2; PinHeader_1x02_P2.54mm_Vertical
POT1, POT2, POT3, POT4, POT5, POT6: 10K; Pot_RightAngle_LongPin_16mm
R24, R25: 1K; R_0805_2012Metric
SW1, SW2, SW3: SW_SPDT; SW_Toggle_SPDT_lugs

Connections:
+3.3VA: POT1.3, POT2.3, POT3.3, POT4.3, POT5.3, POT6.3; also elsewhere on the board
FOOT_SWITCH_1: FS1.2; also elsewhere on the board
FOOT_SWITCH_2: FS2.2; also elsewhere on the board
GND: FS1.1, FS2.1, LED1.1 (K), LED2.1 (K), POT1.1, POT2.1, POT3.1, POT4.1, POT5.1, POT6.1, SW1.2 (B), SW2.2 (B), SW3.2 (B); also elsewhere on the board
LED_1: R24.2; also elsewhere on the board
LED_2: R25.2; also elsewhere on the board
unnamed: LED1.2 (A), R24.1
unnamed: LED2.2 (A), R25.1
POT_1: POT1.2; also elsewhere on the board
POT_2: POT2.2; also elsewhere on the board
POT_3: POT3.2; also elsewhere on the board
POT_4: POT4.2; also elsewhere on the board
POT_5: POT5.2; also elsewhere on the board
POT_6: POT6.2; also elsewhere on the board
SW1_LEFT: SW1.3 (C); also elsewhere on the board
SW1_RIGHT: SW1.1 (A); also elsewhere on the board
SW2_LEFT: SW2.3 (C); also elsewhere on the board
SW2_RIGHT: SW2.1 (A); also elsewhere on the board
SW3_LEFT: SW3.3 (C); also elsewhere on the board
SW3_RIGHT: SW3.1 (A); also elsewhere on the board

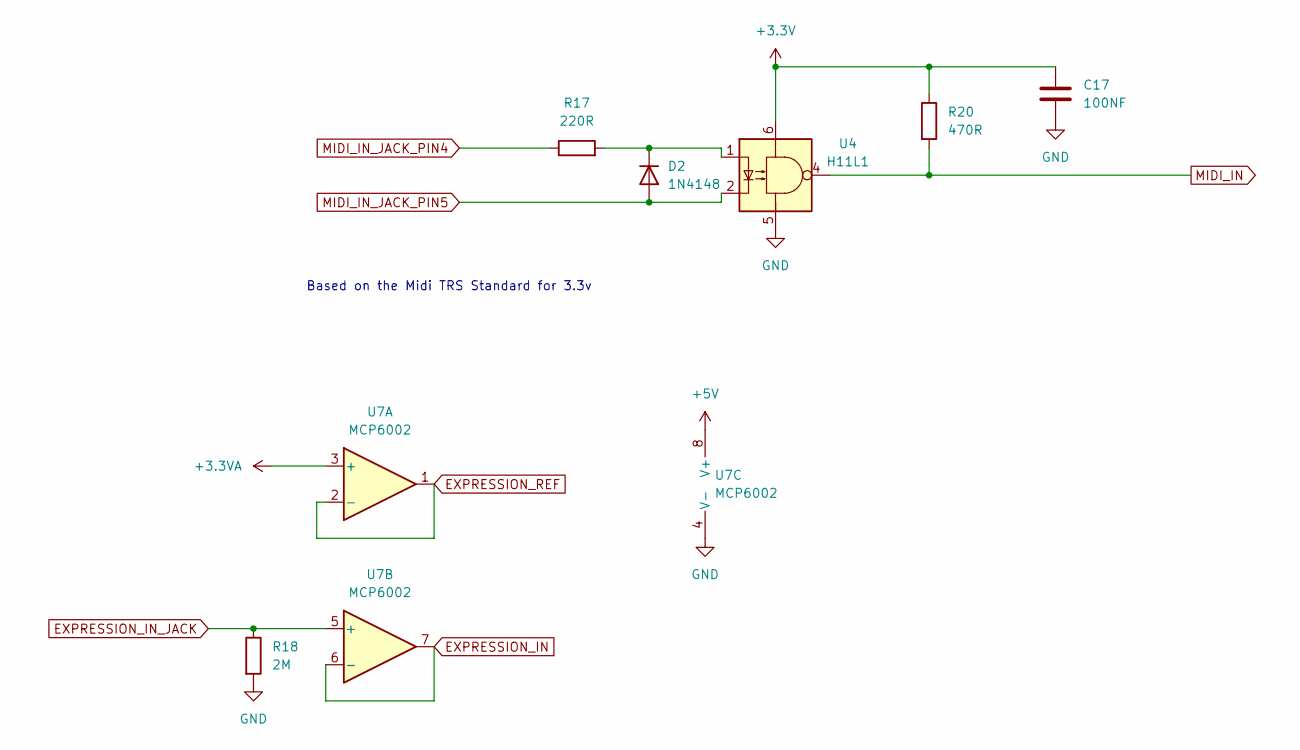
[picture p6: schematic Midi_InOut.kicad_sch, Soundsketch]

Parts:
C17: 100NF; C_0805_2012Metric
D2: 1N4148; D_SOD-123
R17: 220R; R_0805_2012Metric
R18: 2M; R_0805_2012Metric
R20: 470R; R_0805_2012Metric
U4: H11L1; SOP-6_2.54mm
U7: MCP6002; SOIC-8_3.9x4.9mm_P1.27mm

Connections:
+3.3V: C17.1, R20.1, U4.6; also elsewhere on the board
+3.3VA: U7.3 (+); also elsewhere on the board
+5V: U7.8 (V+); also elsewhere on the board
EXPRESSION_IN: U7.6 (-), U7.7; also elsewhere on the board
EXPRESSION_IN_JACK: R18.1, U7.5 (+); also elsewhere on the board
EXPRESSION_REF: U7.1, U7.2 (-); also elsewhere on the board
GND: C17.2, R18.2, U4.5, U7.4 (V-); also elsewhere on the board
MIDI_IN: R20.2, U4.4; also elsewhere on the board
MIDI_IN_JACK_PIN4: R17.1; also elsewhere on the board
MIDI_IN_JACK_PIN5: D2.2 (A), U4.2; also elsewhere on the board
unnamed: D2.1 (K), R17.2, U4.1

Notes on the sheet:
Based on the Midi TRS Standard for 3.3v

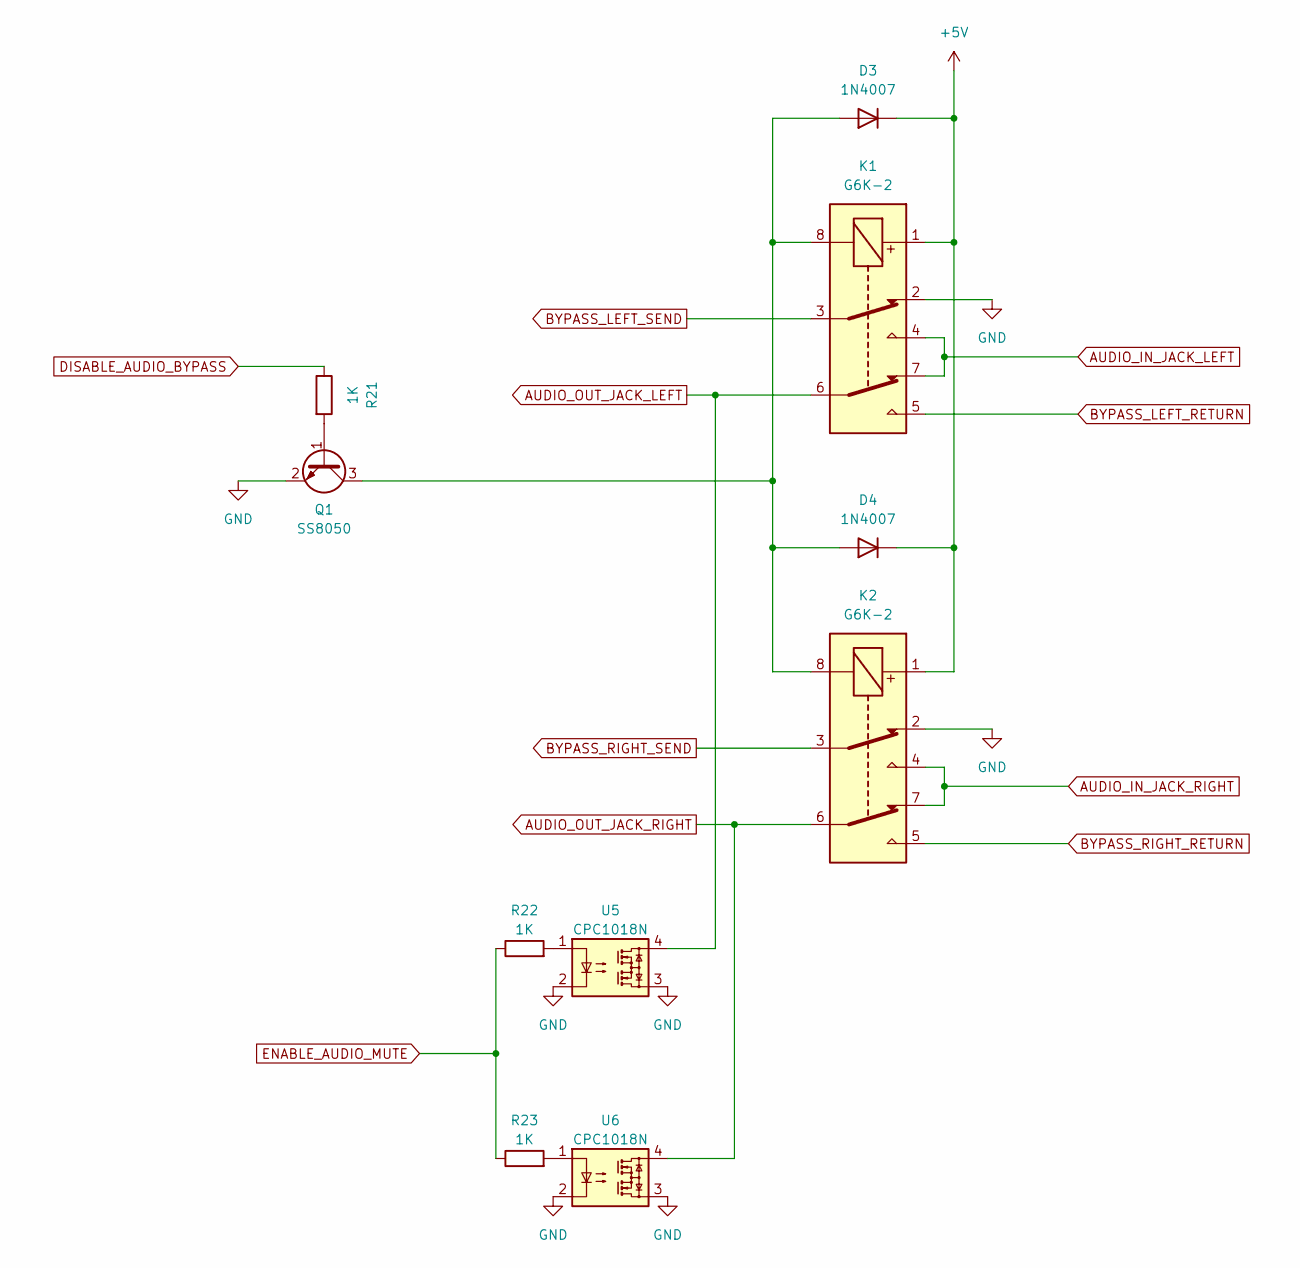
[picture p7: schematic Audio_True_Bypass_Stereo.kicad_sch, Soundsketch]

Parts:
D3, D4: 1N4007; D_SOD-123F
K1, K2: G6K-2; Relay_DPDT_Omron_G6K-2G-Y
Q1: SS8050; SOT-23-3
R21, R22, R23: 1K; R_0805_2012Metric
U5, U6: CPC1018N; SOP-4_3.8x4.1mm_P2.54mm

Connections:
+5V: D3.1 (K), D4.1 (K), K1.1, K2.1; also elsewhere on the board
AUDIO_IN_JACK_LEFT: K1.4, K1.7; also elsewhere on the board
AUDIO_IN_JACK_RIGHT: K2.4, K2.7; also elsewhere on the board
AUDIO_OUT_JACK_LEFT: K1.6, U5.4; also elsewhere on the board
AUDIO_OUT_JACK_RIGHT: K2.6, U6.4; also elsewhere on the board
BYPASS_LEFT_RETURN: K1.5; also elsewhere on the board
BYPASS_LEFT_SEND: K1.3; also elsewhere on the board
BYPASS_RIGHT_RETURN: K2.5; also elsewhere on the board
BYPASS_RIGHT_SEND: K2.3; also elsewhere on the board
DISABLE_AUDIO_BYPASS: R21.1; also elsewhere on the board
ENABLE_AUDIO_MUTE: R22.1, R23.1; also elsewhere on the board
GND: K1.2, K2.2, Q1.2 (E), U5.2, U5.3, U6.2, U6.3; also elsewhere on the board
unnamed: D3.2 (A), D4.2 (A), K1.8, K2.8, Q1.3 (C)
unnamed: Q1.1 (B), R21.2
unnamed: R22.2, U5.1
unnamed: R23.2, U6.1

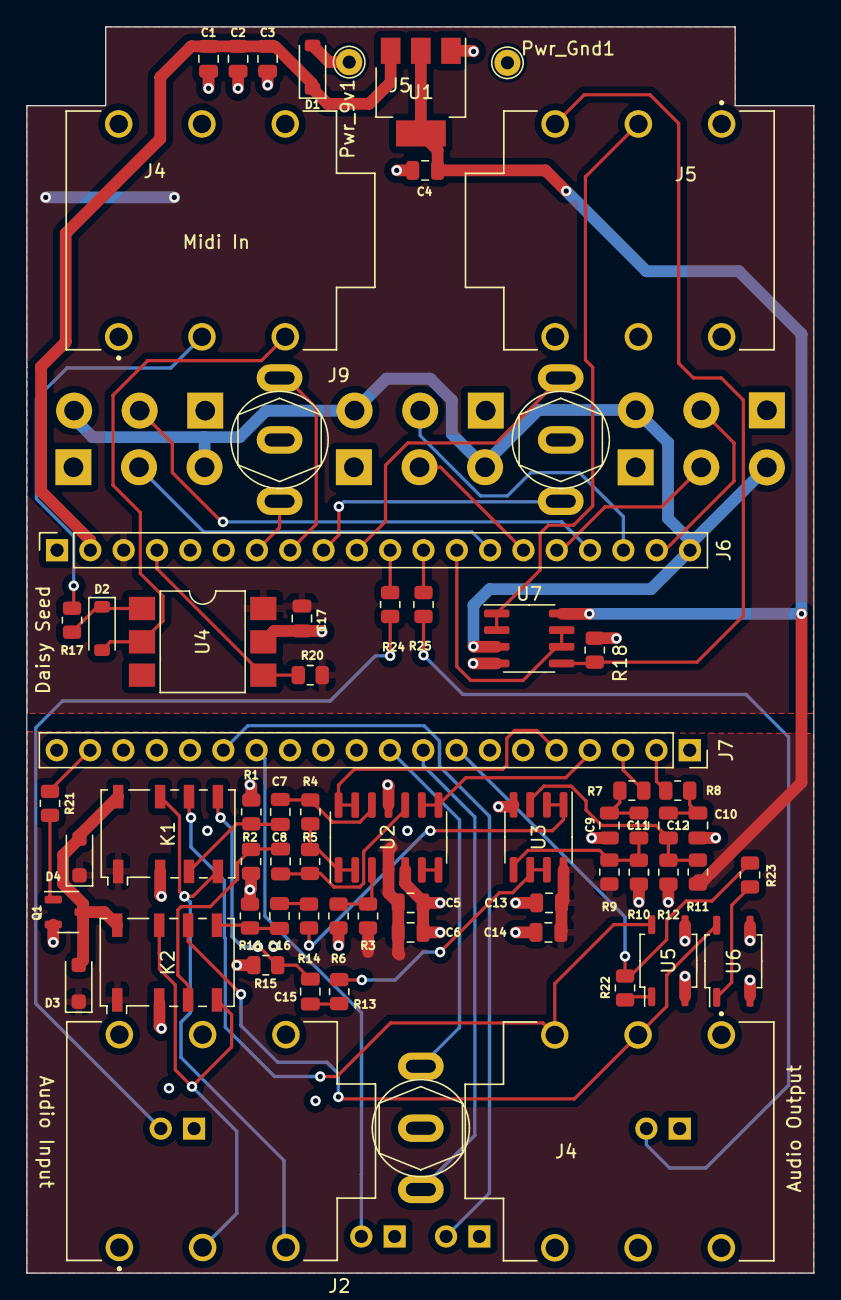
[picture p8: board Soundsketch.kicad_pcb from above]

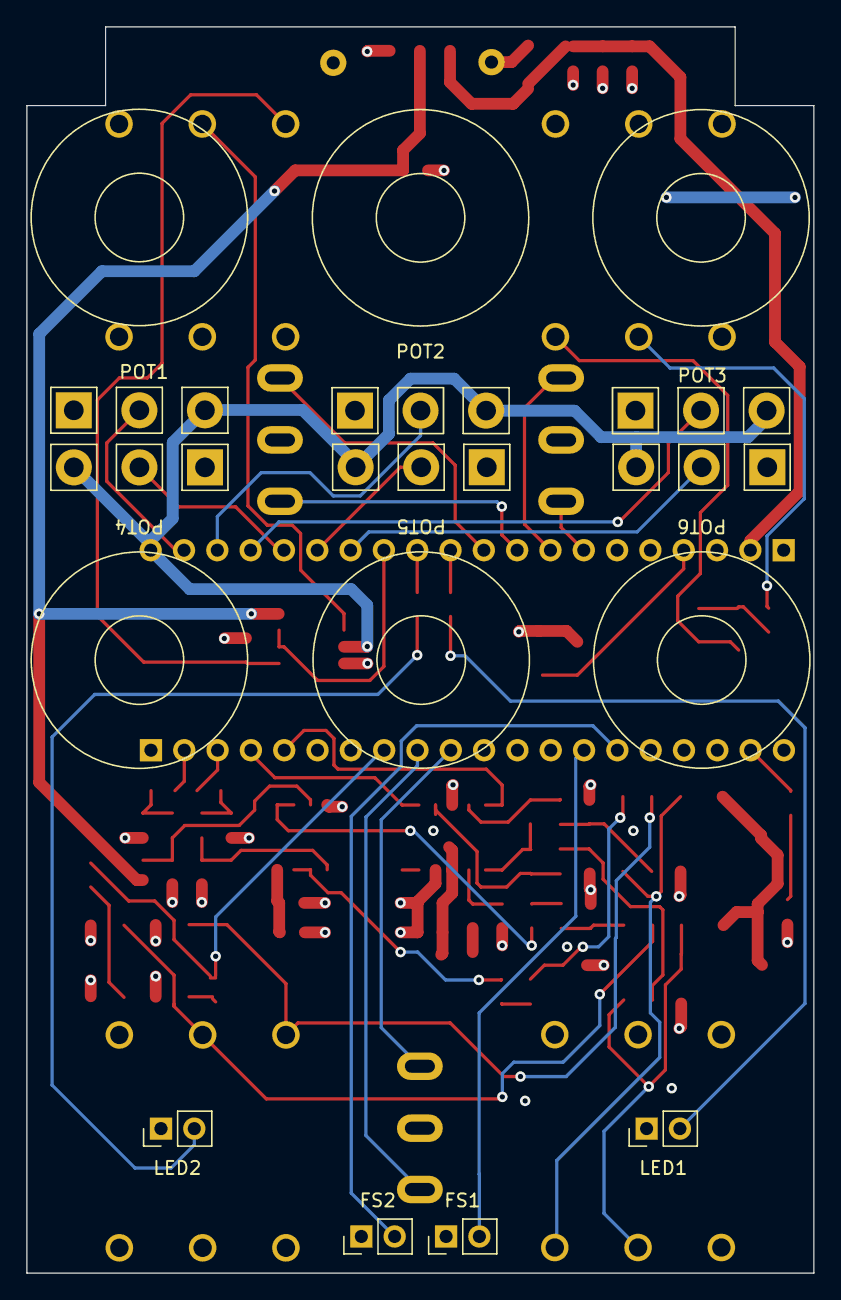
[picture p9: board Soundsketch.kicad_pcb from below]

Board: 4 copper layers, 60.0 x 95.0 mm, 76 parts (10 on the bottom side), 62 nets.

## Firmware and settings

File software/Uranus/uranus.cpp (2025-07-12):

#include "daisy_petal.h"
#include "daisysp.h"
#include "soundsketch.h"
#include "granularplayermod.h"
#include "fm_synth_2op.h"
#include "expressionHandler.h"
#include <q/fx/envelope.hpp>
#include "varSpeedLooper.h"

//
// This is a template for creating a pedal on the GuitarML Funbox_v3/Daisy Seed platform.
// You can start from here to fill out your effects processing and controls.
// Allows for Stereo In/Out, 6 knobs, 3 3-way switches, 2 SPST Footswitches, 2 LEDs.
//
// Keith Bloemer 6/12/2024
//

using namespace daisy;
using namespace daisysp;
using namespace soundsketch; 

// True bypass
GPIO audioBypassTrigger;
GPIO audioMuteTrigger;
bool m_audioBypass;
bool m_audioMute;

bool muteOn = false;
float muteOffTransitionTimeInSeconds = 0.02f;
int muteOffTransitionTimeInSamples;
int samplesTilMuteOff;

bool bypassOn = false;
float bypassToggleTransitionTimeInSeconds = 0.01f;
int bypassToggleTransitionTimeInSamples;
int samplesTilBypassToggle;


// Declare a local daisy_petal for hardware access
DaisyPetal hw;
Parameter grainsize, speed, pitch, mix, feedback, width, expression;
float vpitch1, vpitch2;

float dryMix;
float wetMix;

bool alternateMode;
// Initialize "previous" p values
float pmix, ppitch_raw, pspeed_raw;
float vspeed, vpitch; // These need to be global for alternate funtionality

bool force_reset = false;

bool            bypass;
bool            hold;

bool            pswitch1[2], pswitch2[2], pswitch3[2];
int             switch1[2], switch2[2], switch3[2];

float      current_grainsize; //for smoothing the size param

int mode = 0; // Sets the envelope mode with 2nd toggle

//#define MAX_SAMPLE static_cast<int>(48000.0 / 2) // 0.5 second sample (delay), continually updating with live audio
//#define MAX_SAMPLE_SIZET static_cast<size_t>(MAX_SAMPLE) 
//float DSY_SDRAM_BSS audioSample[MAX_SAMPLE_SIZET];  // Need to initialize this to all 0's
//float audioSample[MAX_SAMPLE_SIZET];  

// 1/2 second at 48kHz
#define MAX_SAMPLE_GRAN 24000
//float DSY_SDRAM_BSS buffer_gran_delay[MAX_SAMPLE_GRAN];
float buffer_gran_delay[MAX_SAMPLE_GRAN]; // use in SRAM, not SDRAM

GranularPlayerMod swarm[2];

daisysp_modified::varSpeedLooper m_looper;
bool m_loop_recorded = false;
int first_count = 0;



//int sample_index;
bool trigger;
int fade_length;  // fade in/fade out audio sample by this many individual samples
int current_grain_buffer_size;

// synth
Adsr       env_;
bool env_gate_ = false;
// global midi key values for granular synth
float note_ = 0.0;
float velocity_ = 0.0;

// LFO for pitch modulation
Oscillator LFO;
float LFO_depth;

bool first_start=true;

Led led1, led2;

// Midi
bool midi_control[6]; // knobs 0-5
float pknobValues[6];
float knobValues[6];


// Expression
ExpressionHandler expHandler;
bool expression_pressed;

int effect_mode = 0;
int synth_mode = 0;

float led2_brightness = 0.0;

int counter = 0;


// FM Synth
static VoiceManager<12> voice_handler;



void SetAudioBypass(bool enabled) {
    m_audioBypass = enabled;
    audioBypassTrigger.Write(!m_audioBypass);
}

void SetAudioMute(bool enabled) {
    m_audioMute = enabled;
    audioMuteTrigger.Write(m_audioMute);
}

void InitTrueBypass(Pin relayPin, Pin mutePin) {
    // Init the HW Audio Bypass
    audioBypassTrigger.Init(relayPin, GPIO::Mode::OUTPUT);
    SetAudioBypass(true);

    // Init the HW Audio Mute
    audioMuteTrigger.Init(mutePin, GPIO::Mode::OUTPUT);
    SetAudioMute(false);

}

bool knobMoved(float old_value, float new_value)
{
    float tolerance = 0.005;
    if (new_value > (old_value + tolerance) || new_value < (old_value - tolerance)) {
        return true;
    } else {
        return false;
    }
}

// Switches1 live mode, sample mode, dry sample loop mode
void updateSwitch1() 
{
    if (pswitch1[0] == true) { 
        effect_mode = 0;
        vpitch1 = 0;
        vpitch2 = 1200;

    } else if (pswitch1[1] == true) {  
        effect_mode = 2;
        vpitch1 = -1200;
        vpitch2 = 1200;

    } else {  
        effect_mode = 1;
        vpitch1 = 0;
        vpitch2 = -1200;
    }   
}

void updateSwitch2() // envelope modes
{
    if (pswitch2[0] == true) {         // left  cosine grain envelope
        mode = 0;
    } else if (pswitch2[1] == true) {  // right   fast attack-decay grain envelope
        mode = 2;
    } else {                           // center  attack- fast decay grain envelope
        mode = 1;
    }

    for (int i = 0; i < 2; i++) {
        swarm[i].setEnvelopeMode(mode);
    }     
}


void updateSwitch3() // left=, center=, right=
{
    if (pswitch3[0] == true) {  // left
        synth_mode = 0;
        

    } else if (pswitch3[1] == true) {  // right
        synth_mode = 2;
        

    } else {   // center
        synth_mode = 1;
    } 

    force_reset = true;   
}


void UpdateButtons()
{

    // (De-)Activate bypass and toggle LED when left footswitch is let go
    if(hw.switches[Soundsketch::FOOTSWITCH_2].FallingEdge())
    {
        if (!expression_pressed && (samplesTilMuteOff < 1)) { // This keeps the pedal from switching bypass when entering/leaving Set Expression mode
            if (alternateMode) {
                alternateMode = false;
                force_reset = true; // force parameter reset to enforce current knob settings when leaving alternate mode
                led2.Set(1.0f);
            } else {
                bypass = !bypass;
                led2.Set(bypass ? 0.0f : 1.0f);

                // Mute audio output to remove pop when relay bypass is switched
                // and start countdowns for triggering the relay bypass, and then unmuting audio
                SetAudioMute(true);
                samplesTilMuteOff = muteOffTransitionTimeInSamples;
                samplesTilBypassToggle = bypassToggleTransitionTimeInSamples;
            }

        }
        expression_pressed = false;
    }


    // Toggle Alternate mode by holding down the left footswitch, if not already in alternate mode and not in bypass
    if(hw.switches[Soundsketch::FOOTSWITCH_2].TimeHeldMs() >= 600 && !alternateMode && !bypass && !hw.switches[Soundsketch::FOOTSWITCH_1].Pressed() && !expression_pressed) { // TODO Check logic here
        alternateMode = true;
        led2.Set(0.5f);  // Dim LED in alternate mode
    }



    // Toggle Expression mode by holding down both footswitches for half a second
    if(hw.switches[Soundsketch::FOOTSWITCH_2].TimeHeldMs() >= 500 && hw.switches[Soundsketch::FOOTSWITCH_1].TimeHeldMs() >= 500 && !expression_pressed ) {
        expHandler.ToggleExpressionSetMode();

        if (expHandler.isExpressionSetMode()) {
            led1.Set(expHandler.returnLed1Brightness());  // Dim LEDs in expression set mode
            led2.Set(expHandler.returnLed2Brightness());  // Dim LEDs in expression set mode

        } else {
            led2.Set(bypass ? 0.0f : 1.0f); 
            led1.Set(0.0f);  
        }
        expression_pressed = true; // Keeps it from switching over and over while held

    }

    // Clear Expression settings by holding down both footswitches for 2 seconds
    if(hw.switches[Soundsketch::FOOTSWITCH_2].TimeHeldMs() >= 2000 && hw.switches[Soundsketch::FOOTSWITCH_1].TimeHeldMs() >= 2000) {
        expHandler.Reset();
        led2.Set(bypass ? 0.0f : 1.0f); 
        led1.Set(0.0f); 

    }


    // Hold current sample when activated (half led brightness when held)
    if(hw.switches[Soundsketch::FOOTSWITCH_1].FallingEdge() && !expression_pressed)
    {
        hold = !hold;
        led1.Set(hold ? 1.0 : 0.0);
    }

    led1.Update();
    led2.Update();
}


void UpdateSwitches()
{
    // Detect any changes in switch positions (3 On-Off-On switches and Dip switches)

    // 3-way Switch 1
    bool changed1 = false;
    for(int i=0; i<2; i++) {
        if (hw.switches[switch1[i]].Pressed() != pswitch1[i]) {
            pswitch1[i] = hw.switches[switch1[i]].Pressed();
            changed1 = true;
        }
    }
    if (changed1 || first_start) 
        updateSwitch1();
    

    // 3-way Switch 2
    bool changed2 = false;
    for(int i=0; i<2; i++) {
        if (hw.switches[switch2[i]].Pressed() != pswitch2[i]) {
            pswitch2[i] = hw.switches[switch2[i]].Pressed();
            changed2 = true;
        }
    }
    if (changed2 || first_start) 
        updateSwitch2();

    // 3-way Switch 3
    bool changed3 = false;
    for(int i=0; i<2; i++) {
        if (hw.switches[switch3[i]].Pressed() != pswitch3[i]) {
            pswitch3[i] = hw.switches[switch3[i]].Pressed();
            changed3 = true;
        }
    }
    if (changed3 || first_start) 
        updateSwitch3();


}



// This runs at a fixed rate, to prepare audio samples
static void AudioCallback(AudioHandle::InputBuffer  in,
                          AudioHandle::OutputBuffer out,
                          size_t                    size)
{
    hw.ProcessAnalogControls();
    hw.ProcessDigitalControls();

    UpdateButtons();
    UpdateSwitches();

    float newExpressionValues[6];

    // Knob 1
    if (!midi_control[0]) {  // If not under midi control or expression control, use knob ADC
        pknobValues[0] = knobValues[0] = grainsize.Process();
    } else if (knobMoved(pknobValues[0], grainsize.Process())) {  // If midi controlled, watch for knob movement to end Midi control
        midi_control[0] = false;
    }

    // Knob 2
    if (!midi_control[1]) {  // If not under midi control, use knob ADC
        pknobValues[1] = knobValues[1] = mix.Process();
    } else if (knobMoved(pknobValues[1], mix.Process())) {  // If midi controlled, watch for knob movement to end Midi control
        midi_control[1] = false;

    }

    // Knob 3
    if (!midi_control[2])   // If not under midi control, use knob ADC
        pknobValues[2] = knobValues[2] = pitch.Process();
    else if (knobMoved(pknobValues[2], pitch.Process()))  // If midi controlled, watch for knob movement to end Midi control
        midi_control[2] = false;

    // Knob 4
    if (!midi_control[3])   // If not under midi control, use knob ADC
        pknobValues[3] = knobValues[3] = feedback.Process();
    else if (knobMoved(pknobValues[3], feedback.Process()))  // If midi controlled, watch for knob movement to end Midi control
        midi_control[3] = false;

    // Knob 5
    if (!midi_control[4])   // If not under midi control, use knob ADC
        pknobValues[4] = knobValues[4] = width.Process();
    else if (knobMoved(pknobValues[4], width.Process()))  // If midi controlled, watch for knob movement to end Midi control
        midi_control[4] = false;


    // Knob 6
    if (!midi_control[5])   // If not under midi control, use knob ADC
        pknobValues[5] = knobValues[5] = speed.Process();
    else if (knobMoved(pknobValues[5], speed.Process()))  // If midi controlled, watch for knob movement to end Midi control
        midi_control[5] = false;


    float vexpression = expression.Process(); // 0 is heel (up), 1 is toe (down)
    expHandler.Process(vexpression, knobValues, newExpressionValues);

    // If in expression set mode, set LEDS accordingly
    if (expHandler.isExpressionSetMode()) {
        led1.Set(expHandler.returnLed1Brightness());
        led2.Set(expHandler.returnLed2Brightness());
    }
  
    float vgrain_size = newExpressionValues[0] * 300 + 1; // 1 to 300ms grain size
    float vmix = newExpressionValues[1];
    float vpitch_raw = newExpressionValues[2];
    float vfeedback = newExpressionValues[3];
    float vwidth = newExpressionValues[4] * 50.0; // Width of 50ms;
    float vspeed_raw = newExpressionValues[5];


    // Handle Knob Changes Here

    // Mix and Alternate Stereo Spread /////////////

    if (knobMoved(pmix, vmix) || force_reset == true) {
        // Handle Normal or Alternate Mode Mix Controls
        //    A cheap mostly energy constant crossfade from SignalSmith Blog
        float x2 = 1.0 - vmix;
        float A = vmix*x2;
        float B = A * (1.0 + 1.4186 * A);
        float C = B + vmix;
        float D = B + x2;

        if (alternateMode == false) {
            wetMix = C * C;
            dryMix = D * D;

        } else {
            float vspread = vmix;
            for (int j = 0; j < 2; j++) {
                swarm[j].setStereoSpread(vspread);
            }

        }
        pmix = vmix;
    }


    // Set pitch in semitones, -12 to + 12 (+/- 1 octave) //////////////
    //  or Alternate Mode LFO Depth

    if (knobMoved(ppitch_raw, vpitch_raw) || force_reset == true) {

        if (alternateMode == false) {
            float vpitch_temp = vpitch_raw * 26 - 13; // -1200 to +1200 pitch in cents (100 cents= 1 semitone), +/- 1 octave range // TODO Might be only hitting semitone below octave, check
            int rounded_pitch = static_cast<int>(vpitch_temp);
            vpitch = rounded_pitch * 100; 

        } else {
            LFO_depth = vpitch_raw * 100; // range of 0 to 100, one semitone
        }
        ppitch_raw = vpitch_raw;
    }

    // Set Grain Speed or Alternate Mode LFO Frequency ////////////////

    if (knobMoved(pspeed_raw, vspeed_raw) || force_reset == true) {

        if (alternateMode == false) {
            vspeed = vspeed_raw * 4.0 - 2.0;  // -2 to +2 speed

        } else {
            LFO.SetFreq(vspeed_raw * vspeed_raw * 6.0); // exponential 0 to 6
        }
        pspeed_raw = vspeed_raw;
    }

    // Set looper feedback
    m_looper.SetFripDecay(vfeedback);


    first_start=false;
    force_reset = false;

    // Process the Audio Buffer //
    for(size_t i = 0; i < size; i++)
    {

        // Handle true bypass relay
        if (samplesTilMuteOff > 0) {
            samplesTilMuteOff -= 1;
            if (samplesTilMuteOff < 1) {
                SetAudioMute(false);
            }
        }

        if (samplesTilBypassToggle > 0) {
            samplesTilBypassToggle -= 1;
            if (samplesTilBypassToggle < 1) {
                SetAudioBypass(bypass);
            }
        }


        float looperOutput = 0.0;

        // Process your signal here
        if(bypass)
        {
            
            out[0][i] = out[1][i] = in[0][i];  // MISO when in bypass

        } else {   

                    // First record workaround, TODO maybe not needed
            if (!m_loop_recorded) {
                if (first_count == 0) {
                    m_looper.TrigRecord(); 
                }
                if (first_count > 23999) {
                    m_loop_recorded = true;
                    m_looper.TrigRecord();
                } else {
                    first_count += 1;
                }
            }

            
            float input = in[0][i];

            // If in FM Synth mode, ignore audio input and use the FM synth
            if (synth_mode == 2) {
                float sum        = 0.f;
                sum        = voice_handler.Process() * 0.05f; // 0.05 for volume reduction
                input   = sum;  
            } 

            // If not in Hold mode, process the next sample into delayline and loop back when it reaches the end
            if (!hold) {

                looperOutput = m_looper.Process(input); // Note: looperOutput is unused

                //float next_sample_feedback = audioSample[sample_index] * vfeedback; //const feedback for now
                //audioSample[sample_index] = next_sample_feedback + input;
                //sample_index += 1;
                //if (sample_index > (MAX_SAMPLE-1)) {
                //    sample_index = 0;

                //}
            }

            /** Processes the granular player.
                \param speed playback speed. 1 is normal speed, 2 is double speed, 0.5 is half speed, etc. Negative values play the sample backwards.
                \param transposition transposition in cents. 100 cents is one semitone. Negative values transpose down, positive values transpose up.
                \param grain_size grain size in milliseconds. 1 is 1 millisecond, 1000 is 1 second. Does not accept negative values. Minimum value is 1.
                \param width width range in milliseconds. Will start each grain envelope at a random location within width range. 0 for no randomized location.
            */
            float gran_out_right = 0.0;
            float gran_out_left = 0.0;

            // If in granular monophonic synth mode, use the midi key to calculate pitch, with middle c (midi key 60) being neutral
            if (synth_mode == 1) {
                // note_ is the midi key, 0 to 127
                vpitch = (note_ - 60.0) * 100.0 ; // override pitch setting, note 0 will be 0, note 61=+100, note 59=-100, etc.
            }

            fonepole(current_grainsize, vgrain_size, .0001f); // decrease decimal to slow down transfer

            // Process pitch LFO
            float LFO_out = LFO.Process() - 1.0; // range -1 to 1
            float pitch_mod = LFO_out * LFO_depth; // range -100 to + 100 based on depth
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
int main(void)
{
    float samplerate;

    hw.Init(true);
    //hw.SetAudioSampleRate(SaiHandle::Config::SampleRate::SAI_96KHZ);
    samplerate = hw.AudioSampleRate();

    //hw.SetAudioBlockSize(4); 

    switch1[0]= Soundsketch::SWITCH_1_UP;
    switch1[1]= Soundsketch::SWITCH_1_DOWN;
    switch2[0]= Soundsketch::SWITCH_2_UP;
    switch2[1]= Soundsketch::SWITCH_2_DOWN;
    switch3[0]= Soundsketch::SWITCH_3_UP;
    switch3[1]= Soundsketch::SWITCH_3_DOWN;

    pswitch1[0]= false;
    pswitch1[1]= false;
    pswitch2[0]= false;
    pswitch2[1]= false;
    pswitch3[0]= false;
    pswitch3[1]= false;

    // True Bypass
    bypassToggleTransitionTimeInSamples = samplerate * bypassToggleTransitionTimeInSeconds;
    muteOffTransitionTimeInSamples = samplerate * muteOffTransitionTimeInSeconds;
    InitTrueBypass(seed::D1, seed::D12); // (relaypin=D1, mutepin=D12)

    samplesTilMuteOff = 0;
    samplesTilBypassToggle = 0;

    //sample_index = 0;
    counter = 0;


    // Init the looper
    m_looper.Init(buffer_gran_delay, MAX_SAMPLE_GRAN);
    m_looper.SetMode(static_cast<daisysp_modified::varSpeedLooper::Mode>(3)); // Frippertronics mode
    
    for(int i = 0; i < MAX_SAMPLE_GRAN; i++) {  // Might not be needed, SRAM buffer inits to 0's?
        buffer_gran_delay[i] = 0.;
    }


    /** Initializes the GranularPlayer module.
        \param sample pointer to the sample to be played
        \param size number of elements in the sample array
        \param sample_rate audio engine sample rate
    */
    // Using a 2 GranularPlayers, which is 4 individual grains.
    // 10 (20 total grains) seems to be hitting a processing limit on Daisy Seed
    // Can handle more than 2 granular players, but going for a 
    // more sparse sound with Uranus.
    swarm[0].Init(buffer_gran_delay, MAX_SAMPLE_GRAN, samplerate, 0.0, 0.5);
    swarm[1].Init(buffer_gran_delay, MAX_SAMPLE_GRAN, samplerate, 0.25, 0.75);


    // monophonic granular synth envelope
    env_.Init(samplerate);
    env_.SetSustainLevel(0.5f);
    env_.SetTime(ADSR_SEG_ATTACK, 0.005f);
    env_.SetTime(ADSR_SEG_DECAY, 0.005f);
    env_.SetTime(ADSR_SEG_RELEASE, 0.2f);

    voice_handler.Init(samplerate);

    voice_handler.SetModulatorRatio(16.0);
    voice_handler.SetCarrierRatio(1.0);
    voice_handler.SetModulatorLevel(0.10);
    voice_handler.SetCarrierLevel(0.5);

    voice_handler.SetCarrierAttack(0.005);
    voice_handler.SetCarrierDecay(0.005);
    voice_handler.SetCarrierSustain(0.5);
    voice_handler.SetCarrierRelease(0.2);

    voice_handler.SetModAttack(0.005);
    voice_handler.SetModDecay(0.005);
    voice_handler.SetModSustain(0.5);
    voice_handler.SetModRelease(0.2);


    alternateMode = false;

    // Start with some stereo spread by default (TODO Maybe change this later)
    for (int j = 0; j < 2; j++) {
        swarm[j].setStereoSpread(0.4);
    }

    pmix = 0.5;            
    wetMix = 0.7;
    dryMix = 0.7; 

    // LFO For Pitch Modulation
    LFO.Init(samplerate);
    LFO.SetFreq(0.25); 
    LFO.SetWaveform(0); // Sine wave
    LFO.SetAmp(2.0); // 
    LFO_depth = 0.0;   // 0 to 200 (2 semitones)

    ppitch_raw = 0.5; // the knob value for pitch param
    vpitch = vpitch1 = vpitch2 = 0.0;  // the actual pitch in cents used to modify granular pitch (-1200 to 1200)

    vspeed = 1.0;  // the grain speed used by the granularplayer
    pspeed_raw = 0.5;

    grainsize.Init(hw.knob[Soundsketch::KNOB_1], 0.0f, 1.0f, Parameter::LINEAR);
    mix.Init(hw.knob[Soundsketch::KNOB_2], 0.0f, 1.0f, Parameter::LINEAR);
    pitch.Init(hw.knob[Soundsketch::KNOB_3], 0.0f, 1.0f, Parameter::LINEAR); 
    feedback.Init(hw.knob[Soundsketch::KNOB_4], 0.01f, 1.0f, Parameter::LINEAR);
    width.Init(hw.knob[Soundsketch::KNOB_5], 0.0f, 1.0f, Parameter::LINEAR); 
    speed.Init(hw.knob[Soundsketch::KNOB_6], 0.0f, 1.0f, Parameter::LINEAR);
    expression.Init(hw.expression, 0.0f, 1.0f, Parameter::LINEAR); 

    // Init the LEDs and set activate bypass
    led1.Init(hw.seed.GetPin(Soundsketch::LED_1),false);
    led1.Update();
    bypass = true;

    led2.Init(hw.seed.GetPin(Soundsketch::LED_2),false);
    led2.Update();
    hold = false;

    // Expression
    expHandler.Init(6);
    expression_pressed = false;

    // Midi
    for( int i = 0; i < 6; ++i ) 
        midi_control[i] = false;  

    hw.InitMidi();
    hw.midi.StartReceive();

    hw.StartAdc();
    hw.StartAudio(AudioCallback);
    while(1)
    {
        hw.midi.Listen();
        // Handle MIDI Events
        while(hw.midi.HasEvents())
        {
            HandleMidiMessage(hw.midi.PopEvent());
        }

    }
}

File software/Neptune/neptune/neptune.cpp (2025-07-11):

// Neptune Reverb/Delay Pedal
// For SoundSketch pedal
//   Note: Funbox code used as starting point, notes may contain old references
// swapped toggle 2 and 3 action, removed persistent storage preset footswitch
// aux footswitch does "swell" action, moves decay (size) to 1.0 as long as held


#include "daisy_petal.h"
#include "daisysp.h"
#include "soundsketch.h"
#include "delayline_reverse.h"
#include "delayline_oct.h"
#include "expressionHandler.h"

#include "../CloudSeed/Default.h"
#include "../CloudSeed/ReverbController.h"
#include "../CloudSeed/FastSin.h"
#include "../CloudSeed/AudioLib/ValueTables.h"
#include "../CloudSeed/AudioLib/MathDefs.h"

using namespace daisy;
using namespace daisysp;
using namespace soundsketch; 

// True bypass
GPIO audioBypassTrigger;
GPIO audioMuteTrigger;
bool m_audioBypass;
bool m_audioMute;

bool muteOn = false;
float muteOffTransitionTimeInSeconds = 0.02f;
int muteOffTransitionTimeInSamples;
int samplesTilMuteOff;

bool bypassOn = false;
float bypassToggleTransitionTimeInSeconds = 0.01f;
int bypassToggleTransitionTimeInSamples;
int samplesTilBypassToggle;

// Declare a local daisy_petal for hardware access
DaisyPetal hw;
::daisy::Parameter rsize, modify, mix, filter, delayTime, delayFDBK, expression;
bool      bypass;
Led led1, led2;

//Tone tone;       // Low Pass
Tone toneOctLP;       // Low Pass for octave delay
//ATone toneHP;    // High Pass
float pfilter;

// Alternate functions
bool alternateMode;

float delayMix;   // Mix vs. Delay Level
float reverbMix;
float dryMix;
float wetMix;

float modAlt;  // Secondary modify function
float preDelayAlt;

bool force_reset;

float  del_FDBK_Override;

float ramp;
bool mode_changed;
bool triggerMode;

bool swell = false;
bool update_switches;


bool            pswitch1[2], pswitch2[2], pswitch3[2];
int             switch1[2], switch2[2], switch3[2];

// Initialize "previous" p values
float psize, pmodify, pdelayTime, pmix;


// Expression
ExpressionHandler expHandler;
bool expression_pressed;

// Midi
bool midi_control[6]; //  just knobs for now
float pknobValues[6]; // Used for Midi control logic

float knobValues[6];
int toggleValues[3];


CloudSeed::ReverbController* reverb = 0;

// This is used in the modified CloudSeed code for allocating
// delay line memory to SDRAM (64MB available on Daisy)
#define CUSTOM_POOL_SIZE (48*1024*1024)
DSY_SDRAM_BSS char custom_pool[CUSTOM_POOL_SIZE];
size_t pool_index = 0;
int allocation_count = 0;
void* custom_pool_allocate(size_t size)
{
        if (pool_index + size >= CUSTOM_POOL_SIZE)
        {
                return 0;
        }
        void* ptr = &custom_pool[pool_index];
        pool_index += size;
        return ptr;
}

// Delay
#define MAX_DELAY static_cast<size_t>(48000 * 4.0f) // 4 second max delay
#define MAX_DELAY_REV static_cast<size_t>(48000 * 8.0f) // 4 second max delay (double for reverse)

DelayLineReverse<float, MAX_DELAY_REV> DSY_SDRAM_BSS delayLineRevLeft;
DelayLineOct<float, MAX_DELAY> DSY_SDRAM_BSS delayLineOctLeft;
DelayLineReverse<float, MAX_DELAY_REV> DSY_SDRAM_BSS delayLineRevRight;
DelayLineOct<float, MAX_DELAY> DSY_SDRAM_BSS delayLineOctRight;


struct delay
{
    DelayLineOct<float, MAX_DELAY> *del;
    DelayLineReverse<float, MAX_DELAY_REV> *delreverse;
    float                        currentDelay;
    float                        delayTarget;
    float                        feedback = 0.0;
    float                        active = false;
    bool                         reverseMode = false;
    float                        level = 1.0;      // Level multiplier of output, added for stereo modulation
    float                        level_reverse = 1.0;      // Level multiplier of output, added for stereo modulation
    bool                         dual_delay = false;
    bool                         secondTapOn = false;
    
    float Process(float in)
    {
        //set delay times
        fonepole(currentDelay, delayTarget, .0002f);
        del->SetDelay(currentDelay);
        delreverse->SetDelay1(currentDelay);

        float del_read = del->Read();

        float read_reverse = delreverse->ReadRev(); // REVERSE

        float read = toneOctLP.Process(del_read);  // LP filter, tames harsh high frequencies on octave, has fading effect for normal/reverse

        float secondTap = 0.0;
        if (secondTapOn) {
            secondTap = del->ReadSecondTap();
        }
        //float read2 = delreverse->ReadFwd();
        if (active) {
            del->Write((feedback * read) + in);
            delreverse->Write((feedback * read) + in);  // Writing the read from fwd/oct delay line allows for combining oct and rev for reverse octave!
            //delreverse->Write((feedback * read2) + in); 
        } else {
            del->Write(feedback * read); // if not active, don't write any new sound to buffer
            delreverse->Write(feedback * read);
            //delreverse->Write((feedback * read2));
        }

        if (dual_delay) {
            return read_reverse * level_reverse * 0.5 + (read + secondTap) * level * 0.5; // Half the volume to keep total level consistent
        } else if (reverseMode) {
            return read_reverse * level_reverse;
        } else {
            return (read + secondTap) * level;
        }
    }
};


// Left channel
delay             delayL;
delay             delayR;  




void SetAudioBypass(bool enabled) {
    m_audioBypass = enabled;
    audioBypassTrigger.Write(!m_audioBypass);
}

void SetAudioMute(bool enabled) {
    m_audioMute = enabled;
    audioMuteTrigger.Write(m_audioMute);
}

void InitTrueBypass(Pin relayPin, Pin mutePin) {
    // Init the HW Audio Bypass
    audioBypassTrigger.Init(relayPin, GPIO::Mode::OUTPUT);
    SetAudioBypass(true);

    // Init the HW Audio Mute
    audioMuteTrigger.Init(mutePin, GPIO::Mode::OUTPUT);
    SetAudioMute(false);

}


bool knobMoved(float old_value, float new_value)
{
    float tolerance = 0.005;
    if (new_value > (old_value + tolerance) || new_value < (old_value - tolerance)) {
        return true;
    } else {
        return false;
    }
}

void updateSwitch1()
{
    // For the different modes, write a preset in the CloudSeed code, and switch presets here
    reverb->ClearBuffers();

    if (toggleValues[0] == 0) { 
        reverb->initFactoryChorus();

    } else if (toggleValues[0] == 2) {
        reverb->initFactoryRubiKaFields();

    } else {                    
        reverb->initFactoryMediumSpace();

    } 
    reverb->SetParameter(::Parameter2::LineCount, 2);
    force_reset = true; // This allows the knob controlled params to be reset without moving the knobs, when a new mode is selected
}
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

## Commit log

2025-07-12 Fixed alternate mode for uranus
    [uranus.cpp]
2026-07-13 Added latest hardware, updated readme
    [Audio_Input_Buffer.kicad_sch, Audio_Output_Buffer.kicad_sch, Audio_True_Bypass_Stereo.kicad_sch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]
2026-07-13 Added pcbway gerbers
    [DaisySeedPedal125b-mod_BOM_PCBWay.xlsx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]
